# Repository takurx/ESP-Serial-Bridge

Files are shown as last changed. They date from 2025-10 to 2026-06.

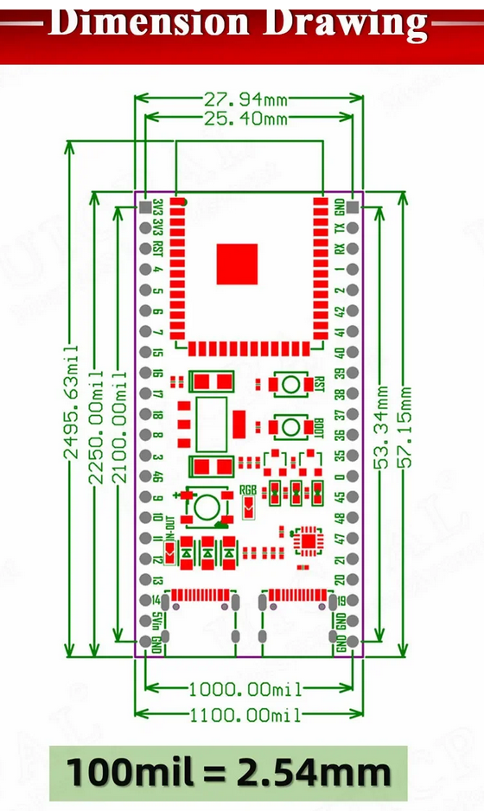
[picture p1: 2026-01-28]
pcb_kicad/esp32s3_serial_bridge_pcb/memo/スクリーンショット 2026-01-28 132533.png

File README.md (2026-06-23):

# ESP32-Serial-Bridge, ESP32S3-Serial-Bridge, 3 port concurrent

---

# Takurx's Notes

## Project Overview

This repository is a fork of [AlphaLima/ESP32-Serial-Bridge](https://github.com/AlphaLima/ESP32-Serial-Bridge) (via [Yuri's fork](https://github.com/yuri-rage/ESP32-Serial-Bridge)).  
It provides a transparent WiFi (TCP/UDP) ↔ multi-UART bridge, targeting both ESP32 and **ESP32-S3** boards.

In addition to the original/Yuri functionality, this fork adds:

- ESP32-S3 (PlatformIO) support for Bridge (Host) and Client
- 3-UART concurrent client (`Kerberos`)
- Hardware flow control (CTS/RTS) pin definitions
- Buffer size tuning for high-throughput stability
- Non-blocking TX with pending queue
- PCB design (KiCad) for ESP32 and ESP32-S3
- 3D-printable enclosure STL files
- Speed test scripts and result logs

---

## Repository Structure

```
ESP-Serial-Bridge/
├── ESP-Serial-Bridge/                        # Original Arduino IDE sketch (ESP32/ESP8266)
│   ├── ESP-Serial-Bridge.ino
│   └── config.h
│
├── ESP32-Serial-WiFi-Client/                 # Arduino IDE single-UART TCP/UDP Client (Yuri)
│   ├── ESP32-Serial-WiFi-Client.ino
│   └── client_config.h
│
├── ESP32-Serial-WiFi-Client-Kerberos/        # Arduino IDE 3-UART concurrent Client (ESP32)
│   ├── ESP32-Serial-WiFi-Client-Kerberos.ino
│   └── client_config.h
│
├── pio-ESP32S3-Serial-WiFi-Bridge/           # PlatformIO Bridge (Host) for ESP32-S3
│   ├── src/main.cpp
│   ├── include/config.h
│   └── platformio.ini
│
├── pio-ESP32S3-Serial-WiFi-Client-Kerberos/  # PlatformIO 3-UART Client (Kerberos) for ESP32-S3
│   ├── src/main.cpp
│   ├── include/client_config.h
│   └── platformio.ini
│
├── pcb_kicad/
│   ├── esp_serial_bridge_pcb/                # KiCad PCB for ESP32
│   └── esp32s3_serial_bridge_pcb/            # KiCad PCB for ESP32-S3 (Kerberos)
│
├── case_3dprint/                             # 3D-printable enclosure STL files
├── speed_test_script/                        # Python speed-test scripts and result logs
└── README.md
```

---

## Recent Updates (Takurx)

### English

#### **Near Full-Speed 3-Port Operation Achieved (Jun 2026)**
Applied buffer optimizations (developed for the Bridge/Host) to the Client (Kerberos) side.  
Result: all three UARTs now operate at **≈ 110,000–115,200 bps** in both directions simultaneously.

- Host → Client (×3 ports): ≈ **110,000 bps** (previously ≈ 13,000 bps)
- Client → Host (×3 ports): ≈ **115,200 bps** (stable)

Key changes:
- `setRxBufferSize(4096)` / `setTxBufferSize(4096)` applied to all UART ports before `begin()`
- Non-blocking TX: `availableForWrite()` used to avoid blocking `write()` calls
- Overflow data stored in a per-channel `txPendingBuf[]` queue and flushed next loop
- Bulk TCP read using `readBytes()` instead of byte-by-byte loop

#### **Buffer Separation: SOFTWAREBUFFERSIZE / HARDWAREBUFFERSIZE (Jun 2026)**
Separated buffer constant into two named constants in `config.h` for clarity:

| Constant | Size | Role |
|---|---|---|
| `HARDWAREBUFFERSIZE` | 4096 B | HardwareSerial internal ring buffer (ISR ← UART FIFO) |
| `SOFTWAREBUFFERSIZE` | 1024 B | Application working buffer (`buf1`, `buf2`, `txPending`) |

Data flow:
```
[UART RX] UART HW FIFO (1024B) → HardwareSerial ring buffer (4096B) → buf2[1024B] → TCP TX
[TCP RX]  TCP RX buffer (lwIP) → buf1[1024B] → HardwareSerial TX ring buffer (4096B) → UART TX
```

#### **pio-ESP32S3-Serial-WiFi-Client-Kerberos — 3-UART PlatformIO Client (Apr 2026)**
Added a PlatformIO version of the 3-UART concurrent client for ESP32-S3.  
Mirrors the same buffer/non-blocking approach as the Bridge Host side.

#### **PCB Design (KiCad) (Mar 2026)**
Added KiCad PCB designs (schematic + layout + Gerber) for:
- `esp_serial_bridge_pcb` — for ESP32 modules
- `esp32s3_serial_bridge_pcb` — for ESP32-S3 modules (Kerberos)

#### **pio-ESP32S3-Serial-WiFi-Bridge — ESP32-S3 PlatformIO Port (Feb 2026)**
New PlatformIO project targeting **RYMCU ESP32-S3-DevKitC-1** (board: `rymcu-esp32-s3-devkitc-1`).

Notable changes from original:
- All 3 UART ports configured with CTS/RTS pins (flow control disabled by default, can be enabled)
- `HARDWAREBUFFERSIZE` = 4096 bytes applied via `setRxBufferSize()` / `setTxBufferSize()`
- Non-blocking TX pending queue (`txPending[]`, `txPendingLen[]`) per UART port
- Bulk TCP read with `readBytes()` instead of 1-byte-at-a-time loop
- Hostname changed to `ESP32-S3`

#### **3-UART Concurrent Client — "Kerberos" (Feb 2026)**
Added `ESP32-Serial-WiFi-Client-Kerberos` (Arduino IDE) and its PlatformIO equivalent.  
Establishes three simultaneous TCP connections (one per UART) to the Bridge Host.

#### **Speed Test Results Summary**

| Date | Config | Host → Client | Client → Host |
|---|---|---|---|
| Dec 2025 | ESP32 AP mode, 1 port, flow ctrl None | ≈ 13,000 bps (drops to 7,000) | ≈ 100,000 bps (stable) |
| Feb 2026 | ESP32-S3 ↔ ESP32-S3, 1 port, flow ctrl ON | avg ≈ 82,000 bps | avg ≈ 20,000 bps |
| Feb 2026 | ESP32-S3 ↔ ESP32-S3, 1 port, flow ctrl OFF | avg ≈ 50,000 bps | avg ≈ 20,000 bps |
| Feb 2026 | ESP32-S3 ↔ ESP32-S3, 3 ports, flow ctrl None | 600–45,000 bps | 7,000–13,000 bps |
| Feb 2026 | 3 ports, flow ctrl ON/OFF | ≈ 13,000 bps avg | ≈ 10,000 bps avg |
| **Jun 2026** | **3 ports, buffer opt. applied to client**, flow ctrl None | **≈ 110,000 bps** | **≈ 115,200 bps** |

#### **Watch Dog Timer Bug Fix (Dec 2025)**
Fixed a critical bug where the system would enter an infinite loop when the Host side crashed and the Watch Dog Timer failed to activate. Now properly handles three scenarios:
1. Client-side crash (Client Reset) → Recovers with input from Host side
2. Host-side crash with quick recovery (Host Reset) → System continues normally
3. Host-side crash without recovery (Host OFF) → Client automatically resets every 30 seconds via Watch Dog Timer

#### **3D-Printable Case (Dec 2025)**
Added STL files for 3D-printable enclosure (box and cover, including v2 versions).

---

### 日本語

#### **3ポート同時フルスピード動作を達成 (2026年6月)**
Bridge（Host）側で開発したバッファ最適化手法をClient（Kerberos）側にも適用。  
全3ポートで**約110,000〜115,200 bps**の双方向同時通信が可能になった。

- Host → Client（×3ポート）: 約 **110,000 bps**（以前は約13,000 bps）
- Client → Host（×3ポート）: 約 **115,200 bps**（安定）

主な変更点：
- `setRxBufferSize(4096)` / `setTxBufferSize(4096)` を全UARTポートの `begin()` 前に適用
- 非ブロッキングTX: `availableForWrite()` でブロッキング `write()` を回避
- 書けなかったデータをポートごとの `txPendingBuf[]` キューに退避し次ループで再送
- TCPの一括読み出し（`readBytes()`）で1バイトずつのループを排除

#### **バッファ定数の分離: SOFTWAREBUFFERSIZE / HARDWAREBUFFERSIZE (2026年6月)**
`config.h` のバッファ定数を2つに分離して明確化：

| 定数 | サイズ | 役割 |
|---|---|---|
| `HARDWAREBUFFERSIZE` | 4096 B | HardwareSerial内部リングバッファ（ISR ← UART FIFO） |
| `SOFTWAREBUFFERSIZE` | 1024 B | アプリ作業バッファ（`buf1`, `buf2`, `txPending`） |

#### **pio-ESP32S3-Serial-WiFi-Client-Kerberos — 3UART PlatformIOクライアント (2026年4月)**
ESP32-S3向け3UART同時クライアントのPlatformIO版を追加。  
BridgeHost側と同じバッファ/非ブロッキング手法を適用。

#### **PCB設計（KiCad）(2026年3月)**
以下のKiCad PCB設計（回路図 + レイアウト + Gerber）を追加：
- `esp_serial_bridge_pcb` — ESP32モジュール用
- `esp32s3_serial_bridge_pcb` — ESP32-S3モジュール（Kerberos）用

#### **pio-ESP32S3-Serial-WiFi-Bridge — ESP32-S3 PlatformIO移植 (2026年2月)**
ESP32-S3（RYMCU ESP32-S3-DevKitC-1）向けの新しいPlatformIOプロジェクト。

主な変更点：
- 全3 UARTポートにCTS/RTSピンを定義（デフォルトはフロー制御無効）
- `HARDWAREBUFFERSIZE` = 4096バイトをRX/TXバッファ両方に適用
- ポートごとの非ブロッキング送信保留キュー（`txPending[]`）を実装
- TCP一括読み出しに変更（`readBytes()` 使用）
- ホスト名を `ESP32-S3` に変更

#### **3UART同時クライアント「Kerberos」(2026年2月)**
3つのTCP接続を同時確立するクライアント `ESP32-Serial-WiFi-Client-Kerberos`（Arduino IDE版）とそのPlatformIO版を追加。

#### **速度テスト結果サマリ**

| 日付 | 構成 | Host → Client | Client → Host |
|---|---|---|---|
| 2025年12月 | ESP32 APモード、1ポート、フロー制御なし | 約13,000 bps（時々7,000に低下） | 約100,000 bps（安定） |
| 2026年2月 | ESP32-S3同士、1ポート、フロー制御あり | 平均 約82,000 bps | 平均 約20,000 bps |
| 2026年2月 | ESP32-S3同士、1ポート、フロー制御なし | 平均 約50,000 bps | 平均 約20,000 bps |
| 2026年2月 | ESP32-S3同士、3ポート同時、フロー制御なし | 600〜45,000 bps | 7,000〜13,000 bps |
| 2026年2月 | 3ポート、フロー制御あり/なし | 平均 約13,000 bps | 平均 約10,000 bps |
| **2026年6月** | **3ポート、クライアント側バッファ最適化適用後**、フロー制御なし | **約110,000 bps** | **約115,200 bps** |

#### **Watch Dog Timer バグ修正 (2025年12月)**
Host側が落ちた時に無限ループに陥り、Watch Dog Timerが効かなかった重大なバグを修正。以下の3つのケースに対応:
1. Client側が落ちた場合（ClientのReset）→ Host側からの入力で回復
2. Host側が落ちてすぐ回復した場合（HostのReset）→ 正常動作
3. Host側が落ちて回復しない場合（HostのOFF）→ 30秒ごとにWatch Dog TimerでClientを自動Reset

#### **3Dプリント用ケース (2025年12月)**
3Dプリント可能なケースのSTLファイルを追加（ボックスとカバー、v2バージョンを含む）。

---

## Hardware: ESP32-S3 Pin Assignment

### Bridge Host (`pio-ESP32S3-Serial-WiFi-Bridge`)

| Port | RX Pin | TX Pin | CTS Pin | RTS Pin | TCP Port | UDP Port |
|---|---|---|---|---|---|---|
| COM0 | GPIO1 | GPIO43 | GPIO16 | GPIO15 | 8880 | 14550 |
| COM1 | GPIO18 | GPIO17 | GPIO10 | GPIO9  | 8881 | 14551 |
| COM2 | GPIO38 | GPIO37 | GPIO36 | GPIO35 | 8882 | 14552 |

- Static IP (AP mode): `192.168.4.1`
- Default SSID: `ssid_esp_uart_bridge3x3`
- Hardware flow control: pins defined, **disabled by default** (comment in code to enable)

---

# Yuri's Notes

This fork is compatible with both the ESP32 and ESP8266.

Because the ESP8266 has some idiosyncrasies with its hardware serial ports, I used SoftwareSerial to implement the ESP8266 bridge.  It is limited to ~115200 baud and will likely prove less reliable than an ESP32. `BLUETOOTH` (hardware limitation) and `PROTOCOL_UDP` (software limitation) are not available on the ESP8266.

As is, the sketch will compile, build, and upload without errors for the ESP32.  Edit `config.h` to configure and build for ESP8266.

There are many configurable parameters in `config.h`. Edit to suit your needs - inline comments should provide clarity.

## Major update, Apr 2023:
* Fixed compatibility with Arduino framework 2.0
* Added compatibility with PlatformIO.
* Implemented `PROTOCOL_UDP` (UDP broadcast)
* `PROTOCOL_TCP` and `PROTOCOL_UDP` can be used simultaneously, though doing so may result in serial traffic conflicts if your client connections are not managed carefully.
* Added `ESP32-Serial-WiFi-Client.ino` in a separate sketch folder to make an ESP32 TCP or UDP client that connects to the ESP-Serial-Bridge. Edit `client_config.h` and upload to a second board.
* Multiple bugs (possible buffer overruns) are fixed in the latest commit(s).
* Latest commits also include some styling/readability edits, though I can easily admit that it isn't the "prettiest" of C++ projects.

---

# ESP32-Serial-Bridge (Original by AlphaLima)

Transparent WiFi (TCP) to all three UART Bridge, supports both AP and STATION WiFi modes. The .ino file is the code for the ESP32. Use Arduino IDE for ESP32 to compile and upload it to the ESP32.
I made this project in order to connect Flight equipment devices devices like (Radio, Vario FLARM), to a Flight Computer (Kobo, Smartphones etc.),  but it is not limited to that. You can use it wherever you want, but on your own risk. Read license file for more details.                                  

===============================================================

Used Libraries: (must be installed in the arduino IDE):

https://github.com/espressif/arduino-esp32

===============================================================

In some cases the memorylayout is to small for this scetch.
If you face this problem you can either disable Bluetooth by removing
#define BLUETOOTH
in config.h 
or change the partition size as described here:
https://desire.giesecke.tk/index.php/2018/04/20/change-partition-size-arduino-ide/

Arduino hardware configuration:

https://github.com/AlphaLima/ESP32-Serial-Bridge/blob/master/Settings.jpg

===============================================================

example usecases:

https://www.youtube.com/watch?v=K2Hia06IMtk

https://www.youtube.com/watch?v=GoSxlQvuAhg

# Hardware (Original ESP32)
here is the wiring diagram recomendation:
https://raw.githubusercontent.com/AlphaLima/ESP32-Serial-Bridge/master/ESP32-SerialBridge.jpg             
Pinning                                                                                     
COM0 Rx <-> GPIO21                                                                               
COM0 Tx <-> GPIO01                                                                                 
COM1 Rx <-> GPIO16                                                                               
COM1 Tx <-> GPIO17                                                                              
COM2 Rx <-> GPIO15                                                                               
COM2 Tx <-> GPIO04                                                                              

NOTE: The PIN assignment has changed and may not look straigt forward (other PINs are marke as Rx/Tx), but this assignment allows to flash via USB also with hooked MAX3232 serial drivers.

I recomend to start your project with a Node32s or compatible evaluation board. For a TTL to RS232 level conversion search google for "TTL RS3232 Converter"

https://tech.scargill.net/wp-content/uploads/2017/05/ESP326.jpg

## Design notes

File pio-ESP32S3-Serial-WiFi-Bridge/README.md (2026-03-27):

# pio-ESP32S3-Serial-WiFi-Bridge

## memo randomly

- data flow
- UART HW FIFO (1024B) → HardwareSerial リングバッファ (4096B) → buf2[1024B] → TCP送信
- TCP RXバッファ（lwIP / WiFiClient内部） → buf1[SOFTWAREBUFFERSIZE] → HardwareSerial TXリングバッファ（既定256B） → UART HW FIFO（ESP32-S3は1024B） → UART TXピン

- buffer description
サイズ	役割
setRxBufferSize(HARDWAREBUFFERSIZE)	4096 bytes	HardwareSerial 内部リングバッファ — ISR が UART FIFO からここへコピーする。loop() が来るまでデータを溜める場所
buf2[NUM_COM][SOFTWAREBUFFERSIZE]	1024 bytes	loop() 内の一時作業バッファ — リングバッファから読み出してTCPへ書くための中継
buf1[NUM_COM][SOFTWAREBUFFERSIZE]	1024 bytes	TCP から読んでシリアルへ書くための中継

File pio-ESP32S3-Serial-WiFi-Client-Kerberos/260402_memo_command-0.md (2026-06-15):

# 260402_memo_command-0.md

## command1
pio-ESP32S3-Serial-WiFi-Bridge/src/main.cppのRX/TXのbufferの拡張、TXのchunk sizeの縮小などの変更した処理を、pio-ESP32S3-Serial-WiFi-Client-Kerberos/src/main.cppの方にも反映させてみてください

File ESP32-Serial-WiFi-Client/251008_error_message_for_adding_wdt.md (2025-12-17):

# 251008_error_message_for_adding_wdt.md

## cycle 1
```
C:\250602_Works\250602_GitLab\ESP-Serial-Bridge\ESP32-Serial-WiFi-Client\ESP32-Serial-WiFi-Client.ino: In function 'void setup()':
C:\250602_Works\250602_GitLab\ESP-Serial-Bridge\ESP32-Serial-WiFi-Client\ESP32-Serial-WiFi-Client.ino:80:23: error: too many arguments to function 'hw_timer_t* timerBegin(uint32_t)'
   80 |     timer = timerBegin(0, 80, true);                  //timer 0, div 80
      |             ~~~~~~~~~~^~~~~~~~~~~~~
In file included from C:\Users\YoshihiroNakagawa\AppData\Local\Arduino15\packages\esp32\hardware\esp32\3.3.0\cores\esp32/esp32-hal.h:98,
                 from C:\Users\YoshihiroNakagawa\AppData\Local\Arduino15\packages\esp32\hardware\esp32\3.3.0\cores\esp32/Arduino.h:44,
                 from C:\250602_Works\250602_GitLab\ESP-Serial-Bridge\ESP32-Serial-WiFi-Client\ESP32-Serial-WiFi-Client.ino:12:
C:\Users\YoshihiroNakagawa\AppData\Local\Arduino15\packages\esp32\hardware\esp32\3.3.0\cores\esp32/esp32-hal-timer.h:35:13: note: declared here
   35 | hw_timer_t *timerBegin(uint32_t frequency);
      |             ^~~~~~~~~~
C:\250602_Works\250602_GitLab\ESP-Serial-Bridge\ESP32-Serial-WiFi-Client\ESP32-Serial-WiFi-Client.ino:81:25: error: too many arguments to function 'void timerAttachInterrupt(hw_timer_t*, void (*)())'
   81 |     timerAttachInterrupt(timer, &resetModule, true);  //attach callback
      |     ~~~~~~~~~~~~~~~~~~~~^~~~~~~~~~~~~~~~~~~~~~~~~~~
C:\Users\YoshihiroNakagawa\AppData\Local\Arduino15\packages\esp32\hardware\esp32\3.3.0\cores\esp32/esp32-hal-timer.h:50:6: note: declared here
   50 | void timerAttachInterrupt(hw_timer_t *timer, void (*userFunc)(void));
      |      ^~~~~~~~~~~~~~~~~~~~
C:\250602_Works\250602_GitLab\ESP-Serial-Bridge\ESP32-Serial-WiFi-Client\ESP32-Serial-WiFi-Client.ino:82:5: error: 'timerAlarmWrite' was not declared in this scope; did you mean 'timerWrite'?
   82 |     timerAlarmWrite(timer, TIMEOUT * 1000, false);    //set time in us
      |     ^~~~~~~~~~~~~~~
      |     timerWrite
C:\250602_Works\250602_GitLab\ESP-Serial-Bridge\ESP32-Serial-WiFi-Client\ESP32-Serial-WiFi-Client.ino:83:5: error: 'timerAlarmEnable' was not declared in this scope; did you mean 'timerAlarm'?
   83 |     timerAlarmEnable(timer);                          //enable interrupt
      |     ^~~~~~~~~~~~~~~~
      |     timerAlarm
exit status 1

Compilation error: too many arguments to function 'hw_timer_t* timerBegin(uint32_t)'
```

## cycle 2
```
C:\250602_Works\250602_GitLab\ESP-Serial-Bridge\ESP32-Serial-WiFi-Client\ESP32-Serial-WiFi-Client.ino:34:1: error: expected ',' or ';' before 'hw_timer_t'
   34 | hw_timer_t *timer = NULL;
      | ^~~~~~~~~~
C:\250602_Works\250602_GitLab\ESP-Serial-Bridge\ESP32-Serial-WiFi-Client\ESP32-Serial-WiFi-Client.ino: In function 'void setup()':
C:\250602_Works\250602_GitLab\ESP-Serial-Bridge\ESP32-Serial-WiFi-Client\ESP32-Serial-WiFi-Client.ino:80:5: error: 'timer' was not declared in this scope; did you mean 'time'?
   80 |     timer = timerBegin(1000000);                       //timer 1MHz
      |     ^~~~~
      |     time
C:\250602_Works\250602_GitLab\ESP-Serial-Bridge\ESP32-Serial-WiFi-Client\ESP32-Serial-WiFi-Client.ino: In function 'void loop()':
C:\250602_Works\250602_GitLab\ESP-Serial-Bridge\ESP32-Serial-WiFi-Client\ESP32-Serial-WiFi-Client.ino:150:16: error: 'timer' was not declared in this scope; did you mean 'time'?
  150 |     timerWrite(timer, 0); //reset timer (feed watchdog)
      |                ^~~~~
      |                time
exit status 1

Compilation error: expected ',' or ';' before 'hw_timer_t'
```

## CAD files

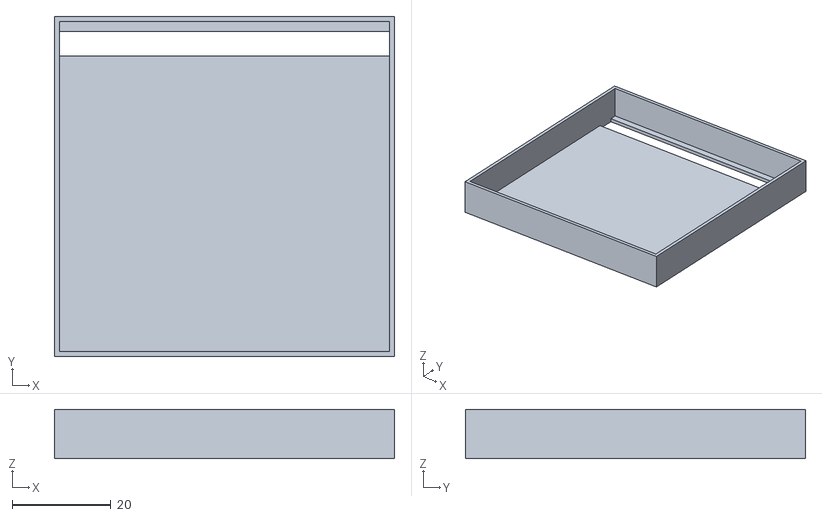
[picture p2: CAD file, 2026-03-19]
case_3dprint/260313_v1_cover_box_ESP32S3_Serial_WiFi_Bridge_Kerberos.stl
69.0 x 69.0 x 10.0

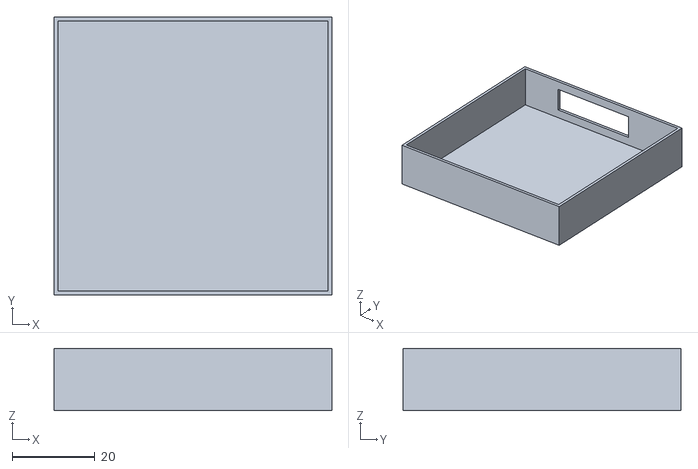
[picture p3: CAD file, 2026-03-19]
case_3dprint/260313_v1_box_ESP32S3_Serial_WiFi_Bridge_Kerberos.stl
67.0 x 67.0 x 15.0

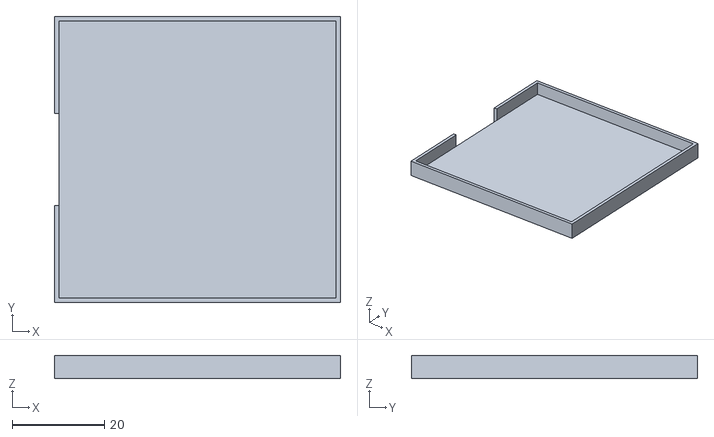
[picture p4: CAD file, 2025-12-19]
case_3dprint/251216_ESP32_uart_bridge_box_cover_v2.stl
62.0 x 62.0 x 5.00

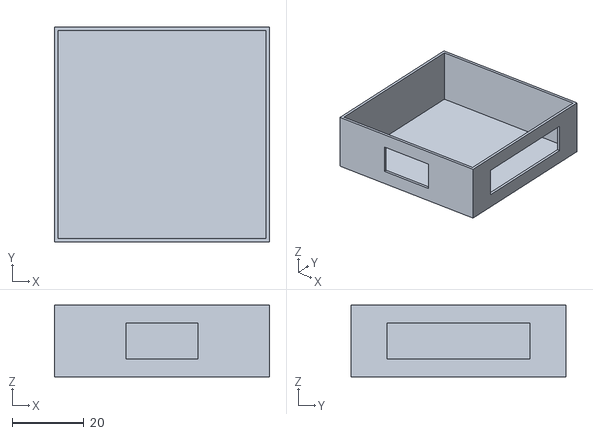
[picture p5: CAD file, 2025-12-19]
case_3dprint/251215_ESP32_uart_bridge_box.stl
60.0 x 60.0 x 20.0

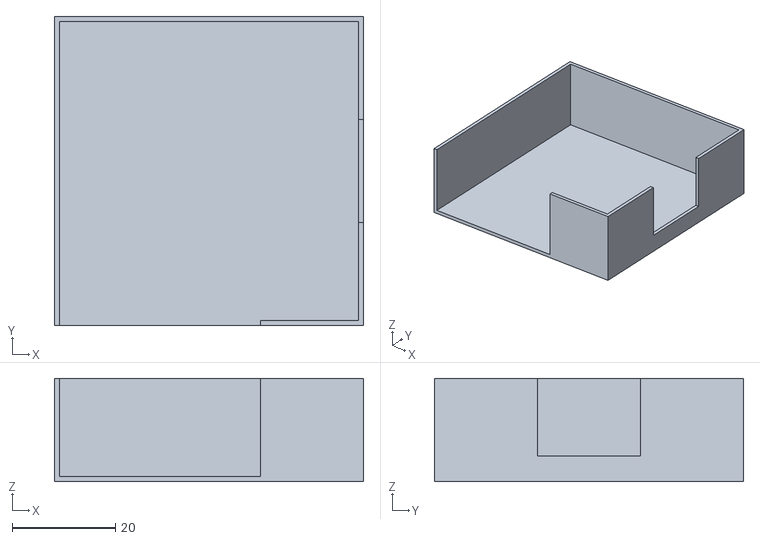
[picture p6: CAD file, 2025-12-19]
case_3dprint/251216_ESP32_uart_bridge_box_v2.stl
60.0 x 60.0 x 20.0

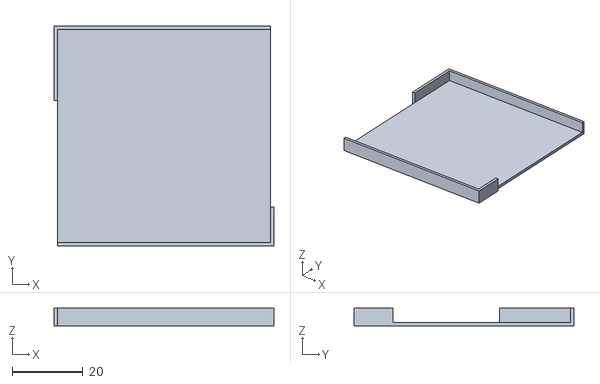
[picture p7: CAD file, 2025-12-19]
case_3dprint/251215_ESP32_uart_bridge_box_cover.stl
62.0 x 62.0 x 5.00

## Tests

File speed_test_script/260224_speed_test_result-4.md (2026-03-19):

# 260224_speed_test_result-4.md

## conditions
- ESP32-S3(host) - ESP32-S3(client)
- pio-ESP32S3-Serial-WiFi-Bridge - pio-ESP32S3-Serial-WiFi-Client-Kerberos

## summary
- flow controlありの方が気持ち速そう
- flow controlあり
  - host -> client, Average 82000 bps
  - host <- client, Average 20000 bps
- flow controlなし
  - host -> client, average 50000 bps
  - host <- client, Average 20000 bps

- ESP32S3の方がhost <- clientの速度が速くて良さそう、また速度が逆の結果ではある
- vs ESP32, 251218
  - Host -> Client: around 13000 bps, たまに7000 pbs
  - Client -> Host: around 100000 bps, 安定

## test1, uart2-com18(host) -> uart2-com29(client), flow control: enabled
- Average 82000 bps, max 108000 bps, min 3500 bps

```
PS C:\250602_Works\250602_GitLab\ESP-Serial-Bridge\speed_test_script> python .\test1_receive_random.py 
3538.78 bps                                                                             
32671.13 bps
77831.97 bps
50005.55 bps
58108.27 bps
59497.78 bps
66487.22 bps
23099.88 bps
38286.39 bps
70974.22 bps
77033.33 bps
80240.13 bps
78274.95 bps
85029.61 bps
80010.75 bps
79048.20 bps
96127.66 bps
89747.27 bps
88844.89 bps
89882.67 bps
96622.58 bps
87002.68 bps
101059.81 bps
105203.01 bps
99724.88 bps
97454.75 bps
102391.41 bps
106546.77 bps
108124.37 bps
87587.94 bps
91371.89 bps
41076.35 bps
78954.53 bps
79964.78 bps
99334.86 bps
67170.67 bps
70372.86 bps
78913.38 bps
78724.66 bps
86967.95 bps
78917.57 bps
79282.09 bps
79094.87 bps
76795.18 bps
88044.04 bps
88784.61 bps
96418.29 bps
96521.74 bps
99536.73 bps
100045.17 bps
95527.63 bps
104900.18 bps
100113.71 bps
48213.42 bps
99794.33 bps
103437.76 bps
101754.82 bps
97536.30 bps
```

## test2, uart2-com18(host) <- uart2-com29(client), flow control: enabled
- Average 20000 bps, max 45000 bps, min 3000 bps

```
PS C:\250602_Works\250602_GitLab\ESP-Serial-Bridge\speed_test_script> python .\test1_receive_random.py
3093.23 bps
45183.01 bps
13730.60 bps
27579.84 bps
16415.60 bps
19765.85 bps
13921.65 bps
16426.43 bps
35207.73 bps
13605.49 bps
13789.07 bps
27787.25 bps
27249.54 bps
13880.87 bps
13761.62 bps
19383.92 bps
27522.93 bps
13814.08 bps
13635.89 bps
13772.15 bps
13753.68 bps
13736.68 bps
32545.46 bps
13737.50 bps
27304.04 bps
13780.52 bps
27373.26 bps
13823.80 bps
16385.23 bps
```

## test3, uart2-com18(host) -> uart2-com29(client), flow control: disabled
- average 50000 bps, max 115000 bps, min 2000 bps

```
PS C:\250602_Works\250602_GitLab\ESP-Serial-Bridge\speed_test_script> python .\test1_receive_random.py
2177.55 bps
115064.37 bps
115139.91 bps
104006.52 bps
37358.19 bps
14603.29 bps
24947.27 bps
20611.27 bps
14594.36 bps
12743.75 bps
20594.07 bps
20288.62 bps
14616.75 bps
20757.68 bps
12822.62 bps
20606.84 bps
28547.43 bps
12657.10 bps
14689.66 bps
20579.03 bps
12744.59 bps
14613.41 bps
20577.66 bps
12628.76 bps
14762.19 bps
12209.61 bps
```

## test4, uart2-com18(host) <- uart2-com29(client), flow control: disabled
- Average 20000 bps, max 100000 bps, min 3000 bps

```
PS C:\250602_Works\250602_GitLab\ESP-Serial-Bridge\speed_test_script> python .\test1_receive_random.py
3307.27 bps
105561.38 bps
9791.88 bps
13586.41 bps
13768.07 bps
20189.73 bps
33626.77 bps
16628.27 bps
19842.49 bps
102550.38 bps
7385.27 bps
13920.94 bps
13824.53 bps
39914.20 bps
13980.38 bps
13536.02 bps
19684.80 bps
28334.70 bps
13812.42 bps
98962.45 bps
90582.25 bps
80638.94 bps
14375.85 bps
32974.44 bps
35345.13 bps
13802.42 bps
52150.37 bps
16809.83 bps
28217.62 bps
13661.30 bps
25906.35 bps
```

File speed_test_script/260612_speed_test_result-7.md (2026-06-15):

# 260612_speed_test_result-7.md

## test1, host x3 -> client x3, ほぼ110000 bps
- com11 -> com8
```
(.venv) PS C:\250602_Works\250602_GitLab\ESP-Serial-Bridge> cd .\speed_test_script\
(.venv) PS C:\250602_Works\250602_GitLab\ESP-Serial-Bridge\speed_test_script> python .\test1_send_random_com11.py         
Traceback (most recent call last):
  File "C:\250602_Works\250602_GitLab\ESP-Serial-Bridge\speed_test_script\test1_send_random_com11.py", line 12, in <module>
    ser.write(os.urandom(1024))
    ~~~~~~~~~^^^^^^^^^^^^^^^^^^
  File "C:\250602_Works\250602_GitLab\ESP-Serial-Bridge\.venv\Lib\site-packages\serial\serialwin32.py", line 321, in write
    win32.GetOverlappedResult(self._port_handle, self._overlapped_write, ctypes.byref(n), True)
    ~~~~~~~~~~~~~~~~~~~~~~~~~^^^^^^^^^^^^^^^^^^^^^^^^^^^^^^^^^^^^^^^^^^^^^^^^^^^^^^^^^^^^^^^^^^
KeyboardInterrupt
(.venv) PS C:\250602_Works\250602_GitLab\ESP-Serial-Bridge\speed_test_script>
```

```
(.venv) PS C:\250602_Works\250602_GitLab\ESP-Serial-Bridge> cd .\speed_test_script\
(.venv) PS C:\250602_Works\250602_GitLab\ESP-Serial-Bridge\speed_test_script> python .\test1_receive_random_com8.py        
78904.37 bps
118948.96 bps
118935.09 bps
108012.09 bps
118890.13 bps
109074.76 bps
118993.17 bps
118980.43 bps
108985.46 bps
119026.42 bps
118868.41 bps
109074.15 bps
118933.56 bps
109093.45 bps
118957.71 bps
118971.28 bps
109073.04 bps
118921.73 bps
118952.31 bps
109042.43 bps
118919.40 bps
109062.70 bps
118947.09 bps
118953.07 bps
109057.76 bps
118981.41 bps
118940.09 bps
109033.70 bps
118941.63 bps
109083.19 bps
118934.55 bps
118943.19 bps
109058.79 bps
118939.84 bps
118973.59 bps
107710.14 bps
118934.79 bps
109054.84 bps
Traceback (most recent call last):
  File "C:\250602_Works\250602_GitLab\ESP-Serial-Bridge\speed_test_script\test1_receive_random_com8.py", line 14, in <module>
    data = ser.read(1024)
  File "C:\250602_Works\250602_GitLab\ESP-Serial-Bridge\.venv\Lib\site-packages\serial\serialwin32.py", line 288, in read
    result_ok = win32.GetOverlappedResult(
        self._port_handle,
        ctypes.byref(self._overlapped_read),
        ctypes.byref(rc),
        True)
KeyboardInterrupt
(.venv) PS C:\250602_Works\250602_GitLab\ESP-Serial-Bridge\speed_test_script> 
```

- com12 -> com9
```
(.venv) PS C:\250602_Works\250602_GitLab\ESP-Serial-Bridge> cd .\speed_test_script\
(.venv) PS C:\250602_Works\250602_GitLab\ESP-Serial-Bridge\speed_test_script> python .\test1_send_random_com12.py      
Traceback (most recent call last):
  File "C:\250602_Works\250602_GitLab\ESP-Serial-Bridge\speed_test_script\test1_send_random_com12.py", line 12, in <module>
    ser.write(os.urandom(1024))
    ~~~~~~~~~^^^^^^^^^^^^^^^^^^
  File "C:\250602_Works\250602_GitLab\ESP-Serial-Bridge\.venv\Lib\site-packages\serial\serialwin32.py", line 321, in write
    win32.GetOverlappedResult(self._port_handle, self._overlapped_write, ctypes.byref(n), True)
    ~~~~~~~~~~~~~~~~~~~~~~~~~^^^^^^^^^^^^^^^^^^^^^^^^^^^^^^^^^^^^^^^^^^^^^^^^^^^^^^^^^^^^^^^^^^
KeyboardInterrupt
(.venv) PS C:\250602_Works\250602_GitLab\ESP-Serial-Bridge\speed_test_script> 
```

```
(.venv) PS C:\250602_Works\250602_GitLab\ESP-Serial-Bridge> cd .\speed_test_script\
(.venv) PS C:\250602_Works\250602_GitLab\ESP-Serial-Bridge\speed_test_script> python .\test1_receive_random_com9.py 
79276.25 bps
118922.99 bps
117907.55 bps
109042.28 bps
118940.42 bps
109035.89 bps
118983.94 bps
118923.49 bps
109093.57 bps
118917.09 bps
118935.20 bps
109072.29 bps
118956.84 bps
109047.62 bps
118960.95 bps
118921.89 bps
109094.30 bps
118927.85 bps
118955.90 bps
109043.92 bps
118968.01 bps
109120.15 bps
118949.45 bps
118958.04 bps
109044.50 bps
118944.34 bps
118955.08 bps
109043.92 bps
118925.41 bps
109046.26 bps
118943.05 bps
118919.54 bps
109048.17 bps
118961.53 bps
118915.12 bps
109058.57 bps
Traceback (most recent call last):
  File "C:\250602_Works\250602_GitLab\ESP-Serial-Bridge\speed_test_script\test1_receive_random_com9.py", line 14, in <module>
    data = ser.read(1024)
  File "C:\250602_Works\250602_GitLab\ESP-Serial-Bridge\.venv\Lib\site-packages\serial\serialwin32.py", line 288, in read
    result_ok = win32.GetOverlappedResult(
        self._port_handle,
        ctypes.byref(self._overlapped_read),
        ctypes.byref(rc),
        True)
KeyboardInterrupt
(.venv) PS C:\250602_Works\250602_GitLab\ESP-Serial-Bridge\speed_test_script> 
```

- com13 -> com14
```
(.venv) PS C:\250602_Works\250602_GitLab\ESP-Serial-Bridge> cd .\speed_test_script\
(.venv) PS C:\250602_Works\250602_GitLab\ESP-Serial-Bridge\speed_test_script> python .\test1_send_random_com13.py   
Traceback (most recent call last):
  File "C:\250602_Works\250602_GitLab\ESP-Serial-Bridge\speed_test_script\test1_send_random_com13.py", line 12, in <module>
    ser.write(os.urandom(1024))
    ~~~~~~~~~^^^^^^^^^^^^^^^^^^
  File "C:\250602_Works\250602_GitLab\ESP-Serial-Bridge\.venv\Lib\site-packages\serial\serialwin32.py", line 321, in write
    win32.GetOverlappedResult(self._port_handle, self._overlapped_write, ctypes.byref(n), True)
    ~~~~~~~~~~~~~~~~~~~~~~~~~^^^^^^^^^^^^^^^^^^^^^^^^^^^^^^^^^^^^^^^^^^^^^^^^^^^^^^^^^^^^^^^^^^
KeyboardInterrupt
(.venv) PS C:\250602_Works\250602_GitLab\ESP-Serial-Bridge\speed_test_script> 
```

```
(.venv) PS C:\250602_Works\250602_GitLab\ESP-Serial-Bridge> cd .\speed_test_script\
(.venv) PS C:\250602_Works\250602_GitLab\ESP-Serial-Bridge\speed_test_script> python .\test1_receive_random_com14.py
79261.24 bps
118221.66 bps
118915.23 bps
109017.20 bps
118945.11 bps
109115.64 bps
118983.42 bps
118951.45 bps
109017.95 bps
118957.06 bps
118947.04 bps
109032.09 bps
118960.98 bps
109067.58 bps
118924.91 bps
118910.89 bps
109045.88 bps
118959.11 bps
118996.94 bps
109061.29 bps
118959.17 bps
109013.42 bps
118957.99 bps
119040.42 bps
109090.22 bps
118948.74 bps
118862.33 bps
109128.65 bps
118914.57 bps
109059.20 bps
118945.14 bps
118914.40 bps
109069.54 bps
112813.63 bps
118958.54 bps
Traceback (most recent call last):
  File "C:\250602_Works\250602_GitLab\ESP-Serial-Bridge\speed_test_script\test1_receive_random_com14.py", line 14, in <module>
    data = ser.read(1024)
  File "C:\250602_Works\250602_GitLab\ESP-Serial-Bridge\.venv\Lib\site-packages\serial\serialwin32.py", line 288, in read
    result_ok = win32.GetOverlappedResult(
        self._port_handle,
        ctypes.byref(self._overlapped_read),
        ctypes.byref(rc),
        True)
KeyboardInterrupt
(.venv) PS C:\250602_Works\250602_GitLab\ESP-Serial-Bridge\speed_test_script> 
```

## test2, host x3 <- client x3、ほぼ115200 bps
- com11 <- com8
```
(.venv) PS C:\250602_Works\250602_GitLab\ESP-Serial-Bridge\speed_test_script> python .\test1_receive_random_com11.py   
115474.55 bps
115230.73 bps
115233.72 bps
115200.21 bps
115255.50 bps
115236.84 bps
115246.14 bps
115226.77 bps
115204.10 bps
115229.06 bps
115240.27 bps
115193.29 bps
115251.45 bps
115220.17 bps
115250.19 bps
115220.74 bps
115210.54 bps
115234.13 bps
115235.09 bps
115225.79 bps
115237.10 bps
115212.96 bps
115213.53 bps
Traceback (most recent call last):
  File "C:\250602_Works\250602_GitLab\ESP-Serial-Bridge\speed_test_script\test1_receive_random_com11.py", line 14, in <module>
    data = ser.read(1024)
  File "C:\250602_Works\250602_GitLab\ESP-Serial-Bridge\.venv\Lib\site-packages\serial\serialwin32.py", line 288, in read
    result_ok = win32.GetOverlappedResult(
        self._port_handle,
        ctypes.byref(self._overlapped_read),
        ctypes.byref(rc),
        True)
KeyboardInterrupt
(.venv) PS C:\250602_Works\250602_GitLab\ESP-Serial-Bridge\speed_test_script> 
```

```
(.venv) PS C:\250602_Works\250602_GitLab\ESP-Serial-Bridge\speed_test_script> python .\test1_send_random_com8.py    
Traceback (most recent call last):
  File "C:\250602_Works\250602_GitLab\ESP-Serial-Bridge\speed_test_script\test1_send_random_com8.py", line 12, in <module>
    ser.write(os.urandom(1024))
    ~~~~~~~~~^^^^^^^^^^^^^^^^^^
  File "C:\250602_Works\250602_GitLab\ESP-Serial-Bridge\.venv\Lib\site-packages\serial\serialwin32.py", line 321, in write
    win32.GetOverlappedResult(self._port_handle, self._overlapped_write, ctypes.byref(n), True)
    ~~~~~~~~~~~~~~~~~~~~~~~~~^^^^^^^^^^^^^^^^^^^^^^^^^^^^^^^^^^^^^^^^^^^^^^^^^^^^^^^^^^^^^^^^^^
KeyboardInterrupt
(.venv) PS C:\250602_Works\250602_GitLab\ESP-Serial-Bridge\speed_test_script> 
```

- com12 <- com9
```
(.venv) PS C:\250602_Works\250602_GitLab\ESP-Serial-Bridge\speed_test_script> python .\test1_receive_random_com12.py
115411.69 bps
115224.60 bps
115257.53 bps
115234.93 bps
115218.16 bps
115222.64 bps
115214.22 bps
115231.25 bps
115216.75 bps
115241.97 bps
115234.88 bps
115230.91 bps
115236.35 bps
115229.60 bps
115224.29 bps
115210.38 bps
115248.00 bps
115235.45 bps
115241.14 bps
115210.90 bps
115238.80 bps
115228.90 bps
Traceback (most recent call last):
  File "C:\250602_Works\250602_GitLab\ESP-Serial-Bridge\speed_test_script\test1_receive_random_com12.py", line 14, in <module>
    data = ser.read(1024)
  File "C:\250602_Works\250602_GitLab\ESP-Serial-Bridge\.venv\Lib\site-packages\serial\serialwin32.py", line 288, in read
    result_ok = win32.GetOverlappedResult(
        self._port_handle,
        ctypes.byref(self._overlapped_read),
        ctypes.byref(rc),
        True)
KeyboardInterrupt
(.venv) PS C:\250602_Works\250602_GitLab\ESP-Serial-Bridge\speed_test_script> 
```

```
(.venv) PS C:\250602_Works\250602_GitLab\ESP-Serial-Bridge\speed_test_script> python .\test1_send_random_com9.py       
Traceback (most recent call last):
  File "C:\250602_Works\250602_GitLab\ESP-Serial-Bridge\speed_test_script\test1_send_random_com9.py", line 12, in <module>
    ser.write(os.urandom(1024))
    ~~~~~~~~~^^^^^^^^^^^^^^^^^^
  File "C:\250602_Works\250602_GitLab\ESP-Serial-Bridge\.venv\Lib\site-packages\serial\serialwin32.py", line 321, in write
    win32.GetOverlappedResult(self._port_handle, self._overlapped_write, ctypes.byref(n), True)
    ~~~~~~~~~~~~~~~~~~~~~~~~~^^^^^^^^^^^^^^^^^^^^^^^^^^^^^^^^^^^^^^^^^^^^^^^^^^^^^^^^^^^^^^^^^^
KeyboardInterrupt
(.venv) PS C:\250602_Works\250602_GitLab\ESP-Serial-Bridge\speed_test_script> 
```

- com13 <- com14
```
(.venv) PS C:\250602_Works\250602_GitLab\ESP-Serial-Bridge\speed_test_script> python .\test1_receive_random_com13.py   
115338.03 bps
115252.66 bps
115220.97 bps
115215.46 bps
115238.10 bps
115212.26 bps
115225.17 bps
115246.17 bps
115200.75 bps
115221.95 bps
115242.35 bps
115218.09 bps
115234.52 bps
115198.51 bps
115234.83 bps
115239.26 bps
115217.88 bps
115226.69 bps
115217.13 bps
115237.95 bps
115214.66 bps
115218.09 bps
115229.70 bps
115233.16 bps
Traceback (most recent call last):
  File "C:\250602_Works\250602_GitLab\ESP-Serial-Bridge\speed_test_script\test1_receive_random_com13.py", line 14, in <module>
    data = ser.read(1024)
  File "C:\250602_Works\250602_GitLab\ESP-Serial-Bridge\.venv\Lib\site-packages\serial\serialwin32.py", line 288, in read
    result_ok = win32.GetOverlappedResult(
        self._port_handle,
        ctypes.byref(self._overlapped_read),
        ctypes.byref(rc),
        True)
KeyboardInterrupt
(.venv) PS C:\250602_Works\250602_GitLab\ESP-Serial-Bridge\speed_test_script> 
```

```
(.venv) PS C:\250602_Works\250602_GitLab\ESP-Serial-Bridge\speed_test_script> python .\test1_send_random_com14.py      
Traceback (most recent call last):
  File "C:\250602_Works\250602_GitLab\ESP-Serial-Bridge\speed_test_script\test1_send_random_com14.py", line 12, in <module>
    ser.write(os.urandom(1024))
    ~~~~~~~~~^^^^^^^^^^^^^^^^^^
  File "C:\250602_Works\250602_GitLab\ESP-Serial-Bridge\.venv\Lib\site-packages\serial\serialwin32.py", line 321, in write
    win32.GetOverlappedResult(self._port_handle, self._overlapped_write, ctypes.byref(n), True)
    ~~~~~~~~~~~~~~~~~~~~~~~~~^^^^^^^^^^^^^^^^^^^^^^^^^^^^^^^^^^^^^^^^^^^^^^^^^^^^^^^^^^^^^^^^^^
KeyboardInterrupt
(.venv) PS C:\250602_Works\250602_GitLab\ESP-Serial-Bridge\speed_test_script> 
```

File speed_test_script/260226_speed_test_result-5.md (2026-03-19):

# 260226_speed_test_result-5.md
- flow controlあり
- host -> client x3, around 13000 bps
- host <- client x3, around 10000 bps

## host -> client x3
- average 13384 bps
- com3 -> com24
```
PS C:\250602_Works\250602_GitLab\ESP-Serial-Bridge\speed_test_script> python .\test1_receive_random_com24.py
8209.64 bps
7414.25 bps
20062.32 bps
26935.83 bps
6636.34 bps
15172.22 bps
12982.51 bps
12805.07 bps
16692.21 bps
17345.38 bps
16577.15 bps
13393.31 bps
12046.95 bps
14719.65 bps
15112.63 bps
13042.45 bps
13585.98 bps
14961.36 bps
11521.83 bps
14277.90 bps
13814.57 bps
12438.71 bps
7486.96 bps
14288.99 bps
6428.01 bps
14013.77 bps
14051.74 bps
6753.16 bps
14257.57 bps
20187.96 bps
6784.34 bps
14204.86 bps
```

- com6 -> com26
- average 12932 bps
```
PS C:\250602_Works\250602_GitLab\ESP-Serial-Bridge\speed_test_script> python .\test1_receive_random_com26.py
6008.63 bps
6799.82 bps
14473.51 bps
14681.49 bps
12820.54 bps
14037.50 bps
13377.27 bps
12397.13 bps
17078.60 bps
12973.63 bps
15192.65 bps
20845.26 bps
12037.01 bps
14087.21 bps
14463.62 bps
12067.55 bps
15422.94 bps
13768.99 bps
12021.22 bps
14093.63 bps
14532.63 bps
12275.56 bps
7308.08 bps
14108.37 bps
6506.10 bps
14620.84 bps
13043.42 bps
7250.04 bps
18901.30 bps
15388.48 bps
6285.60 bps
14982.36 bps
```

- com11 -> com25
- average 13259 bps
```
PS C:\250602_Works\250602_GitLab\ESP-Serial-Bridge\speed_test_script> python .\test1_receive_random_com25.py
8879.58 bps
13973.95 bps
15375.27 bps
6608.19 bps
19321.54 bps
7304.78 bps
12981.72 bps
17184.70 bps
21640.56 bps
15028.63 bps
13885.30 bps
6787.57 bps
15420.29 bps
13748.39 bps
12205.65 bps
7750.47 bps
20424.44 bps
11528.24 bps
15527.29 bps
6983.52 bps
13366.27 bps
7212.68 bps
19545.70 bps
6427.94 bps
14714.85 bps
12953.15 bps
13443.34 bps
13691.78 bps
26823.76 bps
7039.84 bps
```

## host <- client x3
- com3 <- com24
- average 9593 bps
```
PS C:\250602_Works\250602_GitLab\ESP-Serial-Bridge\speed_test_script> python .\test1_receive_random_com3.py  
2467.44 bps
12393.86 bps
9651.24 bps
1273.77 bps
7091.49 bps
7415.35 bps
4311.57 bps
8442.01 bps
8803.40 bps
7868.16 bps
11692.10 bps
7501.33 bps
6823.70 bps
7192.53 bps
7112.49 bps
17219.18 bps
14304.39 bps
7313.47 bps
13512.76 bps
7379.70 bps
12983.04 bps
11752.56 bps
7179.37 bps
7676.67 bps
12436.74 bps
7827.91 bps
12265.62 bps
6812.18 bps
14007.45 bps
7391.31 bps
19870.53 bps
12772.52 bps
7483.83 bps
12121.76 bps
7802.38 bps
12662.78 bps
7401.94 bps
11449.65 bps
7452.99 bps
7325.10 bps
6272.18 bps
13052.69 bps
8398.29 bps
19529.24 bps
11671.10 bps
7644.41 bps
6503.06 bps
7980.66 bps
12588.50 bps
```

- com6 <- com26
- average 9741 bps
```
PS C:\250602_Works\250602_GitLab\ESP-Serial-Bridge\speed_test_script> python .\test1_receive_random_com6.py 
2916.28 bps
12931.56 bps
1106.12 bps
6062.97 bps
8234.07 bps
13083.77 bps
6864.21 bps
18484.52 bps
6970.23 bps
8078.33 bps
12279.64 bps
6898.66 bps
7369.61 bps
12102.50 bps
6739.11 bps
12739.31 bps
7208.17 bps
7644.43 bps
13179.41 bps
6967.38 bps
7337.17 bps
16554.29 bps
8415.66 bps
12828.77 bps
7612.20 bps
17936.72 bps
7244.31 bps
13925.69 bps
12297.82 bps
7343.41 bps
7345.44 bps
13073.34 bps
6455.48 bps
7282.35 bps
6571.36 bps
14457.81 bps
12465.97 bps
7502.33 bps
13434.55 bps
13320.14 bps
6911.68 bps
12357.57 bps
7046.75 bps
7781.63 bps
13130.72 bps
12405.84 bps
6947.99 bps
```

- com11 <- com25
- average 9727 bps
```
PS C:\250602_Works\250602_GitLab\ESP-Serial-Bridge\speed_test_script> python .\test1_receive_random_com11.py
3858.88 bps
9344.13 bps
13865.20 bps
1266.69 bps
7127.89 bps
2872.67 bps
6859.48 bps
18935.49 bps
6522.09 bps
7116.28 bps
7450.46 bps
13141.63 bps
14423.13 bps
6109.01 bps
7891.85 bps
6797.25 bps
19283.64 bps
12657.24 bps
7713.12 bps
12197.82 bps
13515.36 bps
6797.11 bps
7385.73 bps
12410.40 bps
14388.10 bps
7423.75 bps
13052.92 bps
11332.25 bps
7663.14 bps
6884.66 bps
7586.99 bps
12130.18 bps
7663.01 bps
6411.37 bps
15017.45 bps
12330.10 bps
7843.33 bps
12900.34 bps
13846.16 bps
12758.09 bps
6689.49 bps
6721.69 bps
6997.38 bps
7482.40 bps
7049.88 bps
18531.29 bps
6503.12 bps
7575.45 bps
14338.12 bps
```

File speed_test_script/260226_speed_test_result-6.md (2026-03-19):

# 260226_speed_test_result-6.md
- flow controlなし
- host -> client x3, around 13000 bps
- host <- client x3, around 10000 bps

## host -> client x3
- average 13967 bps

- com3 -> com24
```
PS C:\250602_Works\250602_GitLab\ESP-Serial-Bridge\speed_test_script> python .\test1_receive_random_com24.py
7596.18 bps
7175.18 bps
19639.19 bps
18791.18 bps
8122.44 bps
13517.37 bps
12444.75 bps
14206.08 bps
15386.03 bps
12497.33 bps
18692.37 bps
8009.68 bps
10245.09 bps
19383.14 bps
20283.87 bps
25798.97 bps
7614.46 bps
12179.18 bps
13659.21 bps
14593.62 bps
6545.90 bps
14955.96 bps
```

- com6 -> com26
- average 13284 bps
```
PS C:\250602_Works\250602_GitLab\ESP-Serial-Bridge\speed_test_script> python .\test1_receive_random_com26.py
8855.64 bps
14918.95 bps
12900.29 bps
13026.45 bps
8224.27 bps
11504.15 bps
14826.84 bps
20563.80 bps
12833.26 bps
20899.39 bps
14135.63 bps
12717.04 bps
7341.20 bps
14701.79 bps
23033.34 bps
8126.93 bps
14004.12 bps
12100.98 bps
13705.73 bps
8408.98 bps
11714.63 bps
13713.57 bps
```

- com11 -> com25
- average 13502 bps
```
PS C:\250602_Works\250602_GitLab\ESP-Serial-Bridge\speed_test_script> python .\test1_receive_random_com25.py
13206.13 bps
13775.84 bps
12421.58 bps
7115.57 bps
23068.78 bps
12448.88 bps
14314.66 bps
14793.40 bps
16774.85 bps
15289.52 bps
14034.05 bps
12244.31 bps
7660.88 bps
14175.22 bps
19352.01 bps
14613.88 bps
7306.85 bps
17434.52 bps
7816.88 bps
19367.18 bps
6336.11 bps
```

## host <- client x3
- com3 <- com24
- average 9681 bps
```
PS C:\250602_Works\250602_GitLab\ESP-Serial-Bridge\speed_test_script> python .\test1_receive_random_com3.py 
8901.60 bps
7997.97 bps
11294.82 bps
7786.55 bps
6516.94 bps
14254.28 bps
7356.33 bps
12117.76 bps
7438.99 bps
12072.86 bps
14020.42 bps
7028.32 bps
6895.26 bps
13940.02 bps
6530.36 bps
13070.82 bps
8446.79 bps
12321.16 bps
7261.39 bps
12345.44 bps
7917.43 bps
12410.51 bps
6855.78 bps
7573.46 bps
```

- com6 <- com26
- average 9661 bps
```
PS C:\250602_Works\250602_GitLab\ESP-Serial-Bridge\speed_test_script> python .\test1_receive_random_com6.py 
13171.98 bps
6387.59 bps
6977.85 bps
7815.86 bps
12015.40 bps
7368.00 bps
7171.76 bps
17781.45 bps
7190.08 bps
7254.44 bps
14234.08 bps
12990.19 bps
6289.10 bps
7747.92 bps
13075.14 bps
13674.24 bps
6261.42 bps
7250.77 bps
7264.03 bps
19895.93 bps
6244.38 bps
6862.85 bps
7288.81 bps
```

- com11 <- com25
- average 9898 bps
```
PS C:\250602_Works\250602_GitLab\ESP-Serial-Bridge\speed_test_script> python .\test1_receive_random_com11.py
8809.17 bps
7930.15 bps
12917.67 bps
7220.33 bps
12540.10 bps
7058.84 bps
7330.00 bps
17718.81 bps
7344.16 bps
6985.82 bps
6799.95 bps
7366.29 bps
16610.63 bps
7271.77 bps
7397.20 bps
7422.21 bps
17724.66 bps
7355.78 bps
6795.71 bps
7430.07 bps
19842.56 bps
```

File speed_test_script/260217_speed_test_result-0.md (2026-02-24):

# 260217 speed test result-0.md

## summary
各3ポート115200bpsで乱数を送る設定で、
Host x3→Client x3、各ポート600～45000 bps
Host x3←Client x3、各ポート7000～13000 bps

## log
PS C:\250602_Works\250602_GitLab\ESP-Serial-Bridge\speed_test_script> python .\test1_send_random_com3.py 

```
PS C:\250602_Works\250602_GitLab\ESP-Serial-Bridge\speed_test_script> python .\test1_receive_random_com24.py
18438.48 bps
7046.29 bps
14998.02 bps
11171.20 bps
8423.18 bps
6088.77 bps
14289.46 bps
14576.61 bps
41591.50 bps
10851.66 bps
35944.44 bps
43047.30 bps
20026.29 bps
17155.59 bps
23068.79 bps
27488.68 bps
34778.67 bps
35380.30 bps
42927.72 bps
5207.19 bps
10445.57 bps
51102.54 bps
40900.88 bps
29376.52 bps
37808.99 bps
34725.71 bps
33842.46 bps
1886.22 bps
22817.30 bps
6857.54 bps
42528.76 bps
9538.48 bps
15077.19 bps
37033.00 bps
41198.40 bps
5732.22 bps
18341.88 bps
16878.69 bps
24089.49 bps
40504.66 bps
13089.11 bps
6885.19 bps
15327.69 bps
17158.91 bps
23841.09 bps
29943.14 bps
44392.31 bps
31958.74 bps
8831.94 bps
9596.12 bps
8879.92 bps
10159.72 bps
16278.26 bps
14570.18 bps
10309.02 bps
1562.54 bps
10182.12 bps
693.48 bps
1863.45 bps
9416.21 bps
11106.05 bps
1822.02 bps
5685.66 bps
36568.68 bps
24094.63 bps
18866.83 bps
22560.98 bps
2049.90 bps
12749.07 bps
26033.16 bps
31136.82 bps
34049.18 bps
40418.31 bps
25735.79 bps
33861.97 bps
38974.56 bps
27327.49 bps
39183.08 bps
10093.79 bps
37144.24 bps
22968.86 bps
4860.04 bps
3689.12 bps
8440.19 bps
35191.58 bps
41239.16 bps
6713.72 bps
19615.23 bps
35368.83 bps
8548.06 bps
35747.21 bps
35170.27 bps
15427.37 bps
40580.89 bps
6941.64 bps
Traceback (most recent call last):
  File "C:\250602_Works\250602_GitLab\ESP-Serial-Bridge\speed_test_script\test1_receive_random_com24.py", line 14, in <module>
    data = ser.read(1024)
  File "C:\Users\YoshihiroNakagawa\AppData\Local\Programs\Python\Python313\Lib\site-packages\serial\serialwin32.py", line 288, in read       
    result_ok = win32.GetOverlappedResult(
        self._port_handle,
        ctypes.byref(self._overlapped_read),
        ctypes.byref(rc),
        True)
KeyboardInterrupt
PS C:\250602_Works\250602_GitLab\ESP-Serial-Bridge\speed_test_script>
```

PS C:\250602_Works\250602_GitLab\ESP-Serial-Bridge\speed_test_script> python .\test1_send_random_com6.py 
```
PS C:\250602_Works\250602_GitLab\ESP-Serial-Bridge\speed_test_script> python .\test1_receive_random_com25.py
3608.05 bps
16634.48 bps
6964.20 bps
15116.31 bps
14447.81 bps
49124.92 bps
17170.91 bps
24860.05 bps
41293.79 bps
27618.06 bps
18333.90 bps
17646.28 bps
20757.44 bps
28493.10 bps
36066.76 bps
41394.78 bps
12789.82 bps
9985.83 bps
41606.60 bps
29199.37 bps
26612.35 bps
30477.90 bps
35920.92 bps
38399.32 bps
9807.60 bps
2545.70 bps
28102.79 bps
3395.70 bps
41529.12 bps
9255.03 bps
15725.83 bps
34768.33 bps
41235.76 bps
5163.99 bps
29411.64 bps
14478.47 bps
37041.93 bps
14445.31 bps
11087.71 bps
12843.74 bps
16682.40 bps
26466.59 bps
18028.76 bps
33509.54 bps
30485.67 bps
16474.28 bps
12868.30 bps
7085.19 bps
9785.82 bps
5158.77 bps
3514.60 bps
10019.25 bps
1709.81 bps
8737.63 bps
4180.61 bps
1562.83 bps
15730.90 bps
2756.88 bps
11482.82 bps
2268.70 bps
2661.87 bps
35706.72 bps
19841.27 bps
25652.22 bps
23546.50 bps
1755.98 bps
22741.42 bps
39641.63 bps
29664.57 bps
37731.29 bps
42511.45 bps
19171.37 bps
38014.77 bps
49408.08 bps
26240.56 bps
44401.39 bps
3603.80 bps
35238.18 bps
19217.33 bps
5151.43 bps
3509.08 bps
3141.32 bps
42958.71 bps
41207.92 bps
16680.70 bps
13015.06 bps
33801.54 bps
14114.28 bps
25914.42 bps
43284.48 bps
5085.16 bps
```

PS C:\250602_Works\250602_GitLab\ESP-Serial-Bridge\speed_test_script> python .\test1_send_random_com11.py
```
PS C:\250602_Works\250602_GitLab\ESP-Serial-Bridge\speed_test_script> python .\test1_receive_random_com26.py
15857.36 bps
10815.55 bps
8371.26 bps
5944.79 bps
11133.65 bps
17935.29 bps
38607.58 bps
16756.47 bps
35914.60 bps
41303.26 bps
35082.89 bps
12612.27 bps
18397.46 bps
29716.19 bps
38256.72 bps
29591.31 bps
41386.07 bps
6872.46 bps
27073.61 bps
4159.11 bps
42313.41 bps
45472.52 bps
25492.54 bps
30666.91 bps
37233.10 bps
37184.62 bps
8720.30 bps
4140.51 bps
17469.84 bps
3730.49 bps
41754.83 bps
9231.85 bps
9290.59 bps
59889.66 bps
41453.69 bps
9041.79 bps
17376.19 bps
20114.69 bps
35642.15 bps
14564.71 bps
27550.65 bps
2780.25 bps
15251.15 bps
19051.05 bps
20969.00 bps
35228.54 bps
38883.97 bps
20580.78 bps
8697.07 bps
10882.13 bps
11897.34 bps
11625.58 bps
17784.51 bps
7932.75 bps
8228.15 bps
1637.52 bps
9084.25 bps
830.52 bps
3534.85 bps
1586.00 bps
10614.30 bps
2827.40 bps
16059.65 bps
2296.62 bps
2556.43 bps
34266.43 bps
19718.35 bps
18737.32 bps
24028.41 bps
3650.17 bps
18603.18 bps
33570.93 bps
37993.20 bps
36663.16 bps
45536.30 bps
26640.42 bps
32899.05 bps
43789.63 bps
27207.73 bps
35739.98 bps
3861.61 bps
44181.03 bps
21793.84 bps
8655.47 bps
6571.69 bps
7086.59 bps
2884.42 bps
38387.62 bps
18813.47 bps
16898.82 bps
39893.19 bps
16033.03 bps
25557.34 bps
16661.85 bps
```

PS C:\250602_Works\250602_GitLab\ESP-Serial-Bridge\speed_test_script> python .\test1_send_random_com24.py 

PS C:\250602_Works\250602_GitLab\ESP-Serial-Bridge\speed_test_script> python .\test1_receive_random_com3.py 
14669.03 bps
15661.48 bps
19257.90 bps
34876.60 bps
15286.43 bps
15410.23 bps
16248.38 bps
7791.71 bps
20527.65 bps
11691.29 bps
7389.27 bps
6266.90 bps
8060.07 bps
12979.58 bps
6615.63 bps
3437.97 bps
14200.15 bps
13377.67 bps
6181.14 bps
3699.86 bps
13922.97 bps
12545.38 bps
6850.23 bps
6340.55 bps
7959.66 bps
12520.17 bps
7204.28 bps
7148.66 bps
6590.51 bps
6467.96 bps
7640.82 bps
13570.47 bps
6387.90 bps
6987.18 bps
6694.92 bps
6725.29 bps
7570.47 bps
13577.24 bps
12281.96 bps
6544.59 bps
6890.15 bps
7804.24 bps
6382.55 bps
7111.57 bps
6783.89 bps
7305.08 bps
12229.71 bps
6597.65 bps
3716.93 bps
18343.96 bps
6741.65 bps
7327.07 bps
6926.89 bps
6998.46 bps
12595.52 bps
6389.69 bps
7662.57 bps
13014.65 bps
6144.32 bps
7359.22 bps
7584.18 bps
12298.30 bps
6992.35 bps
6911.21 bps
7150.58 bps
14670.52 bps
5564.98 bps
8467.26 bps
13857.12 bps
6795.72 bps
6606.32 bps
6826.43 bps
7117.28 bps
14238.91 bps
5873.73 bps
7944.53 bps
6844.91 bps
9889.39 bps
7011.30 bps
6235.78 bps
7622.52 bps
12558.52 bps
7351.78 bps
6951.60 bps
13772.55 bps
19834.26 bps
8729.37 bps
17811.78 bps
5333.63 bps
13487.42 bps
6955.94 bps
7391.08 bps
11155.46 bps
8067.38 bps
6897.81 bps
7351.09 bps
11743.86 bps
3651.72 bps
6236.70 bps
15138.36 bps
6773.23 bps
6643.21 bps
6760.79 bps
7326.70 bps
13117.82 bps
6275.93 bps
7601.98 bps
6495.59 bps
7312.12 bps
6018.77 bps
7950.81 bps
12610.50 bps
6946.18 bps
7208.70 bps
6509.75 bps
7055.15 bps
13861.49 bps
6801.47 bps
11647.10 bps
7564.08 bps
6855.40 bps
7337.36 bps
6173.69 bps
6794.24 bps
7312.04 bps
6501.55 bps
6354.63 bps
3713.12 bps
12641.42 bps
3647.35 bps
12861.16 bps
6227.98 bps
7698.21 bps
6555.30 bps
13047.16 bps
7870.41 bps
12543.04 bps
6698.80 bps
6207.74 bps

PS C:\250602_Works\250602_GitLab\ESP-Serial-Bridge\speed_test_script> python .\test1_send_random_com25.py

PS C:\250602_Works\250602_GitLab\ESP-Serial-Bridge\speed_test_script> python .\test1_receive_random_com6.py 
32623.65 bps
6543.21 bps
16819.17 bps
33493.77 bps
36696.06 bps
4026.19 bps
16514.15 bps
16534.51 bps
15839.52 bps
7898.33 bps
12473.38 bps
7224.74 bps
6623.15 bps
6751.67 bps
6567.28 bps
7117.74 bps
6509.31 bps
7418.94 bps
6640.19 bps
7185.92 bps
12867.94 bps
6885.92 bps
7094.84 bps
12737.19 bps
3599.01 bps
13128.23 bps
6431.20 bps
7071.45 bps
6823.90 bps
7211.80 bps
12424.09 bps
7635.47 bps
6700.63 bps
7331.95 bps
11862.81 bps
7864.58 bps
11034.91 bps
7129.67 bps
3726.81 bps
6646.86 bps
12316.09 bps
7768.36 bps
7242.53 bps
11911.28 bps
6731.92 bps
6539.02 bps
8101.78 bps
7142.69 bps
12376.85 bps
6965.36 bps
6407.34 bps
8063.39 bps
12600.14 bps
6815.78 bps
6631.64 bps
12355.35 bps
3820.30 bps
11382.84 bps
7375.71 bps
3654.48 bps
13020.48 bps
6835.18 bps
14053.98 bps
6031.12 bps
6163.03 bps
8671.91 bps
13011.82 bps
13315.37 bps
3440.84 bps
7233.23 bps
13671.43 bps
12363.75 bps
6993.44 bps
7216.38 bps
6616.05 bps
7199.03 bps
13310.06 bps
6336.50 bps
7273.40 bps
6678.67 bps
3637.17 bps
12491.73 bps
14528.18 bps
12779.55 bps
7010.74 bps
36059.33 bps
5409.38 bps
11893.50 bps
3243.29 bps
29024.93 bps
4799.97 bps
13548.68 bps
6908.28 bps
7277.12 bps
12611.14 bps
7817.24 bps
11340.84 bps
3801.88 bps
12591.33 bps
6695.37 bps
7424.93 bps
13325.29 bps
6712.58 bps
7211.53 bps
6276.22 bps
7053.50 bps
6697.27 bps
7049.59 bps
6698.97 bps
13042.46 bps
7407.51 bps
6977.62 bps
12591.64 bps
6545.12 bps
7045.85 bps
6562.75 bps
6816.28 bps
7986.85 bps
12715.29 bps
6709.05 bps
6612.01 bps
6375.54 bps
8190.90 bps
6910.28 bps
6048.35 bps
7453.78 bps
7139.39 bps
6790.07 bps
12977.12 bps
7319.35 bps
6084.09 bps
3465.69 bps
7675.17 bps
13709.74 bps
12450.13 bps
6165.95 bps
7055.90 bps
7553.36 bps
7580.09 bps
11397.82 bps
7603.78 bps

PS C:\250602_Works\250602_GitLab\ESP-Serial-Bridge\speed_test_script> python .\test1_send_random_com26.py 

PS C:\250602_Works\250602_GitLab\ESP-Serial-Bridge\speed_test_script> python .\test1_receive_random_com11.py                                 
10395.75 bps
17412.74 bps
36930.72 bps
15161.89 bps
13139.09 bps
16222.59 bps
13283.70 bps
13149.50 bps
19187.56 bps
7186.78 bps
6269.58 bps
3617.63 bps
6679.59 bps
13654.13 bps
6879.78 bps
6309.52 bps
7522.37 bps
6372.28 bps
7502.03 bps
11680.27 bps
6383.95 bps
3877.44 bps
15987.50 bps
7257.86 bps
8237.50 bps
12599.88 bps
7017.56 bps
7120.99 bps
7187.98 bps
12654.28 bps
6480.07 bps
6248.57 bps
3855.88 bps
13007.27 bps
6977.74 bps
12388.83 bps
6875.12 bps
7869.61 bps
6798.29 bps
6432.26 bps
6545.13 bps
7018.43 bps
7253.23 bps
13679.90 bps
12201.50 bps
7134.41 bps
6693.35 bps
6648.81 bps
6878.12 bps
7687.94 bps
12868.48 bps
7267.11 bps
6137.04 bps
3458.01 bps
7630.40 bps
13110.25 bps
6304.94 bps
7649.16 bps
17907.72 bps
7316.05 bps
6642.29 bps
6089.93 bps
8101.33 bps
6966.00 bps
12650.21 bps
7220.60 bps
6507.96 bps
16036.87 bps
6754.51 bps
12283.36 bps
6975.67 bps
7243.66 bps
6987.79 bps
6181.59 bps
7431.15 bps
6442.65 bps
6806.66 bps
7239.38 bps
11529.82 bps
3841.21 bps
13296.71 bps
6633.92 bps
18177.94 bps
7512.78 bps
10823.29 bps
6719.28 bps
8596.83 bps
14089.38 bps
9799.28 bps
6179.87 bps
8302.93 bps
10344.92 bps
10173.00 bps
13012.03 bps
7087.38 bps
12796.97 bps
6891.97 bps
7404.99 bps
12005.51 bps
13987.11 bps
6543.57 bps
3612.86 bps
6836.12 bps
12415.33 bps
7043.44 bps
7044.97 bps
7420.29 bps
7032.16 bps
12243.34 bps
6784.32 bps
5944.11 bps
7185.66 bps
8007.18 bps
6685.42 bps
7304.84 bps
12724.22 bps
6398.54 bps
7909.15 bps
12035.79 bps
6274.70 bps
3699.40 bps
7067.04 bps
12614.30 bps
6965.85 bps
6835.63 bps
3484.47 bps
6927.07 bps
13013.27 bps
6253.18 bps
7563.83 bps
6354.09 bps
3717.84 bps
13456.84 bps
11117.38 bps
8250.52 bps
6718.96 bps

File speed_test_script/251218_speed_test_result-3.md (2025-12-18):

# 251218_speed_test_result-3.md

## result3
- Host -> Client: around 13000 bps, たまに7000 pbs
- Client -> Host: around 100000 bps, 安定

### test3-1
- Host -> Client: around 13000 bps, たまに7000 pbs
```
PS C:\250602_Works\250602_GitLab\ESP-Serial-Bridge\speed_test_script> python .\test1_receive_random.py
2329.42 bps
16523.34 bps
13072.70 bps
14283.74 bps
13004.31 bps
13610.43 bps
15456.41 bps
12438.58 bps
7194.69 bps
14002.30 bps
12974.87 bps
13865.76 bps
13491.13 bps
6765.28 bps
13316.72 bps
7418.59 bps
```

### test3-2
- Client -> Host: around 100000 bps, 安定
```
PS C:\250602_Works\250602_GitLab\ESP-Serial-Bridge\speed_test_script> python .\test1_receive_random.py
2272.60 bps
100997.60 bps
101210.61 bps
100990.90 bps
101178.83 bps
100955.79 bps
101211.82 bps
101224.42 bps
101149.83 bps
101099.87 bps
101183.12 bps
101104.42 bps
101218.29 bps
101217.81 bps
101093.97 bps
101109.94 bps
101140.87 bps
101307.08 bps
```

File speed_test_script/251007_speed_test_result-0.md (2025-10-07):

# 251007_speed_test_result-0.md

## test1
- Host -> Client: around 11000 bps, 1/10
- Client -> Host: around 80000 bps

### test1 detail
- Host -> Client: around 11000 bps, 1/10
```
PS C:\250602_Works\250602_GitLab\ESP-Serial-Bridge\speed_test_script> python .\test1_receive_random.py
9437.34 bps
10642.07 bps
6163.63 bps
14873.13 bps
11102.08 bps
11005.70 bps
5552.57 bps
10833.07 bps
11031.34 bps
5211.61 bps
5783.82 bps
16435.98 bps
10812.21 bps
9828.91 bps
12238.48 bps
5398.71 bps
11187.61 bps
```
- Client -> Host: around 80000 bps
```
PS C:\250602_Works\250602_GitLab\ESP-Serial-Bridge\speed_test_script> python .\test1_receive_random.py
76537.87 bps
80721.85 bps
80845.42 bps
80787.46 bps
81025.16 bps
80693.60 bps
80843.86 bps
80668.67 bps
80694.41 bps
80951.30 bps
80942.55 bps
80923.27 bps
80717.47 bps
```

## test2
- Host -> Client, around 11000 bps, 1/10
- Client -> Host, around 115200 bps, Ok

### test2, detail
- Host -> Client, around 11000 bps, 1/10
```
PS C:\250602_Works\250602_GitLab\ESP-Serial-Bridge\speed_test_script> python .\test1_receive_random.py
8613.45 bps
7017.59 bps
13569.80 bps
6700.04 bps
13826.51 bps
14297.73 bps
13348.43 bps
13311.04 bps
13815.43 bps
6572.14 bps
```
- Client -> Host, around 115200 bps, Ok
```
PS C:\250602_Works\250602_GitLab\ESP-Serial-Bridge\speed_test_script> python .\test1_receive_random.py
2490.32 bps
103051.81 bps
101330.02 bps
101190.01 bps
101395.86 bps
101285.53 bps
101177.61 bps
101078.65 bps
101285.08 bps
100570.91 bps
100694.02 bps
```

## test3
- Host -> Client, around 13000 bps, 1/10
- Client -> Host, around 115200 bps

### test3, detail
- Host -> Client, around 13000 bps, 1/10
```
PS C:\250602_Works\250602_GitLab\ESP-Serial-Bridge\speed_test_script> python .\test1_receive_random.py
8643.42 bps
13705.61 bps
7663.88 bps
13088.96 bps
12960.40 bps
13315.06 bps
14086.15 bps
13497.89 bps
14034.07 bps
13409.55 bps
```

- Client -> Host, around 115200 bps
```
PS C:\250602_Works\250602_GitLab\ESP-Serial-Bridge\speed_test_script> python .\test1_receive_random.py
825.76 bps
101699.98 bps
101086.60 bps
100784.28 bps
101176.80 bps
101184.19 bps
101181.45 bps
100977.22 bps
101200.93 bps
101220.15 bps
```

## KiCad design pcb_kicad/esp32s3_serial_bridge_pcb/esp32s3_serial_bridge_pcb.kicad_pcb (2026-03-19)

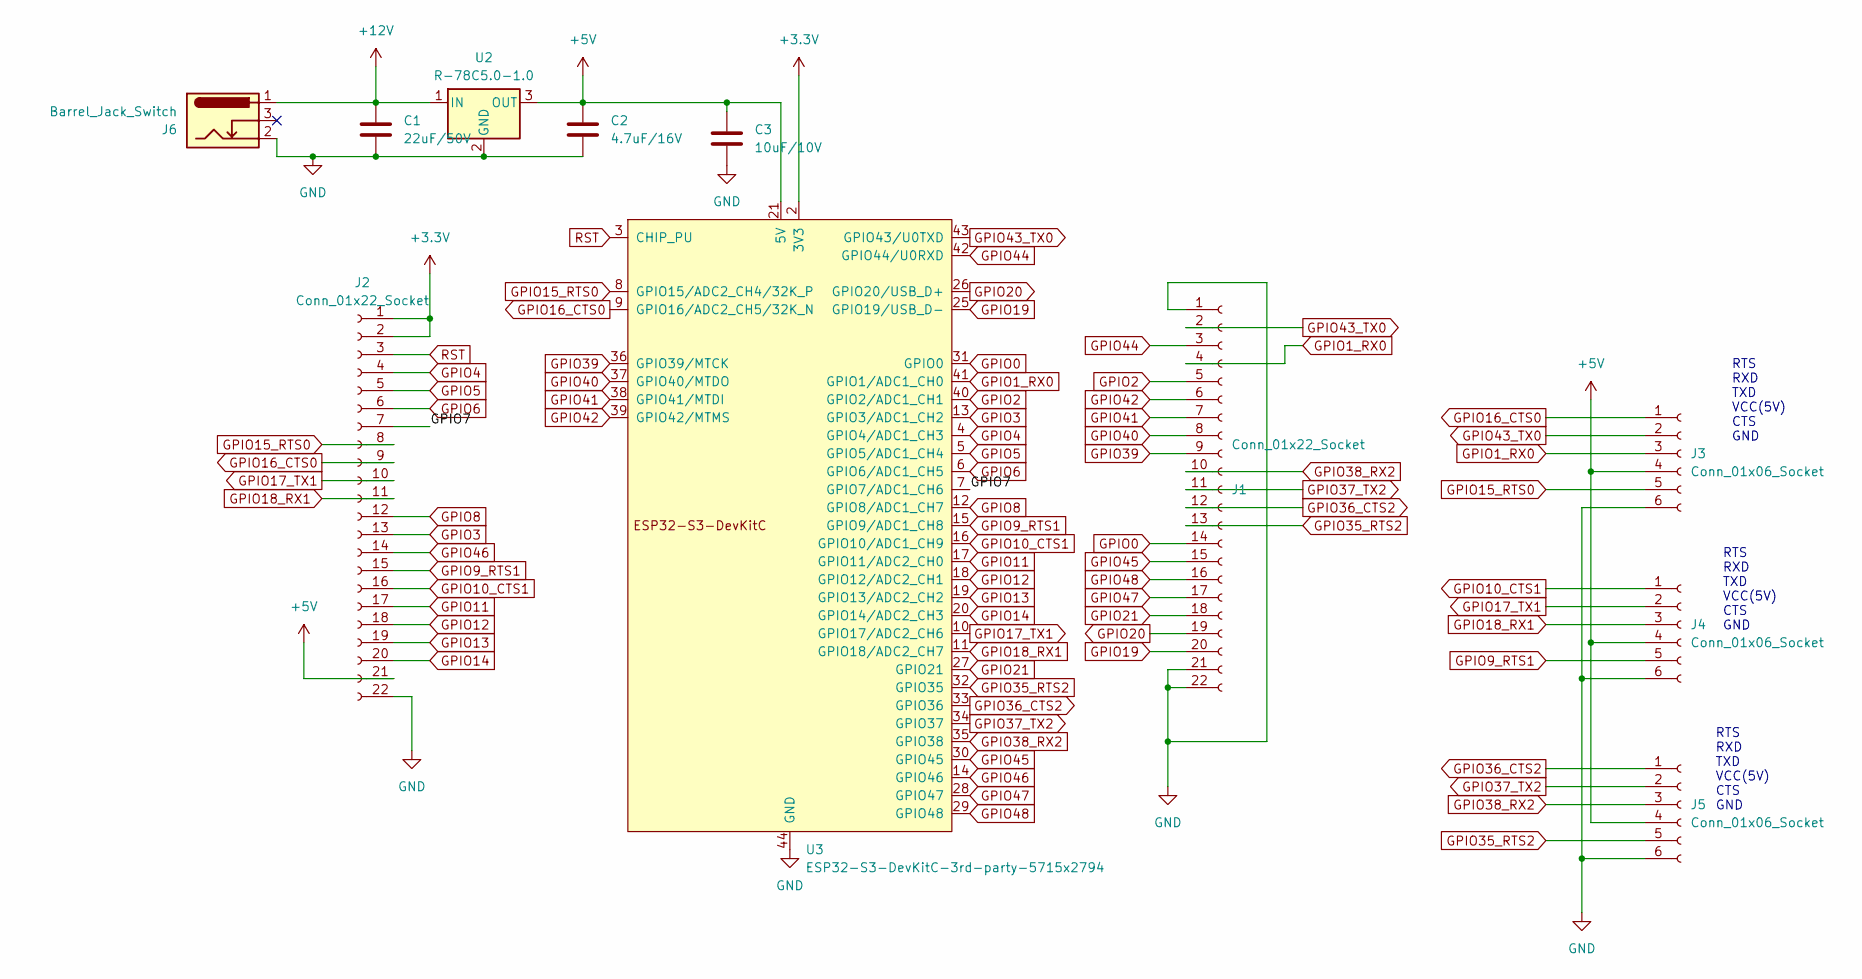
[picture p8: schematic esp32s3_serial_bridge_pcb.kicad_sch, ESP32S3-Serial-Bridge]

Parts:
C1: 22uF/50V; C_2220_5750Metric_Pad1.97x5.40mm_HandSolder
C2: 4.7uF/16V; C_1210_3225Metric_Pad1.33x2.70mm_HandSolder
C3: 10uF/10V; C_1210_3225Metric_Pad1.33x2.70mm_HandSolder
J1, J2: Conn_01x22_Socket; PinHeader_1x22_P2.54mm_Vertical
J3, J4, J5: Conn_01x06_Socket; PinHeader_1x06_P2.54mm_Vertical
J6: Barrel_Jack_Switch; BarrelJack_Horizontal
U2: R-78C5.0-1.0; Converter_DCDC_RECOM_R-78E-0.5_THT
U3: ESP32-S3-DevKitC-3rd-party-5715x2794; ESP32-S3-DevKitC_3rd_party_5715x2794

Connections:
+3.3V: J2.1, J2.2, U3.1 (3V3), U3.2 (3V3)
+5V: C2.1, C3.1, J2.21, J3.4, J4.4, J5.4, U2.3 (OUT), U3.21 (5V)
+12V: C1.1, J6.1, U2.1 (IN)
/GPIO7: J2.7, U3.7 (GPIO7/ADC1_CH6)
GND: C1.2, C2.2, C3.2, J1.1, J1.21, J1.22, J2.22, J3.6, J4.6, J5.6, J6.2, U2.2 (GND), U3.22 (GND), U3.23 (GND), U3.24 (GND), U3.44 (GND)
GPIO0: J1.14, U3.31 (GPIO0)
GPIO1_RX0: J1.4, J3.3, U3.41 (GPIO1/ADC1_CH0)
GPIO2: J1.5, U3.40 (GPIO2/ADC1_CH1)
GPIO3: J2.13, U3.13 (GPIO3/ADC1_CH2)
GPIO4: J2.4, U3.4 (GPIO4/ADC1_CH3)
GPIO5: J2.5, U3.5 (GPIO5/ADC1_CH4)
GPIO6: J2.6, U3.6 (GPIO6/ADC1_CH5)
GPIO8: J2.12, U3.12 (GPIO8/ADC1_CH7)
GPIO9_RTS1: J2.15, J4.5, U3.15 (GPIO9/ADC1_CH8)
GPIO10_CTS1: J2.16, J4.1, U3.16 (GPIO10/ADC1_CH9)
GPIO11: J2.17, U3.17 (GPIO11/ADC2_CH0)
GPIO12: J2.18, U3.18 (GPIO12/ADC2_CH1)
GPIO13: J2.19, U3.19 (GPIO13/ADC2_CH2)
GPIO14: J2.20, U3.20 (GPIO14/ADC2_CH3)
GPIO15_RTS0: J2.8, J3.5, U3.8 (GPIO15/ADC2_CH4/32K_P)
GPIO16_CTS0: J2.9, J3.1, U3.9 (GPIO16/ADC2_CH5/32K_N)
GPIO17_TX1: J2.10, J4.2, U3.10 (GPIO17/ADC2_CH6)
GPIO18_RX1: J2.11, J4.3, U3.11 (GPIO18/ADC2_CH7)
GPIO19: J1.20, U3.25 (GPIO19/USB_D-)
GPIO20: J1.19, U3.26 (GPIO20/USB_D+)
GPIO21: J1.18, U3.27 (GPIO21)
GPIO35_RTS2: J1.13, J5.5, U3.32 (GPIO35)
GPIO36_CTS2: J1.12, J5.1, U3.33 (GPIO36)
GPIO37_TX2: J1.11, J5.2, U3.34 (GPIO37)
GPIO38_RX2: J1.10, J5.3, U3.35 (GPIO38)
GPIO39: J1.9, U3.36 (GPIO39/MTCK)
GPIO40: J1.8, U3.37 (GPIO40/MTDO)
GPIO41: J1.7, U3.38 (GPIO41/MTDI)
GPIO42: J1.6, U3.39 (GPIO42/MTMS)
GPIO43_TX0: J1.2, J3.2, U3.43 (GPIO43/U0TXD)
GPIO44: J1.3, U3.42 (GPIO44/U0RXD)
GPIO45: J1.15, U3.30 (GPIO45)
GPIO46: J2.14, U3.14 (GPIO46)
GPIO47: J1.17, U3.28 (GPIO47)
GPIO48: J1.16, U3.29 (GPIO48)
RST: J2.3, U3.3 (CHIP_PU)

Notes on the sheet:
RTS RXD TXD VCC(5V) CTS GND

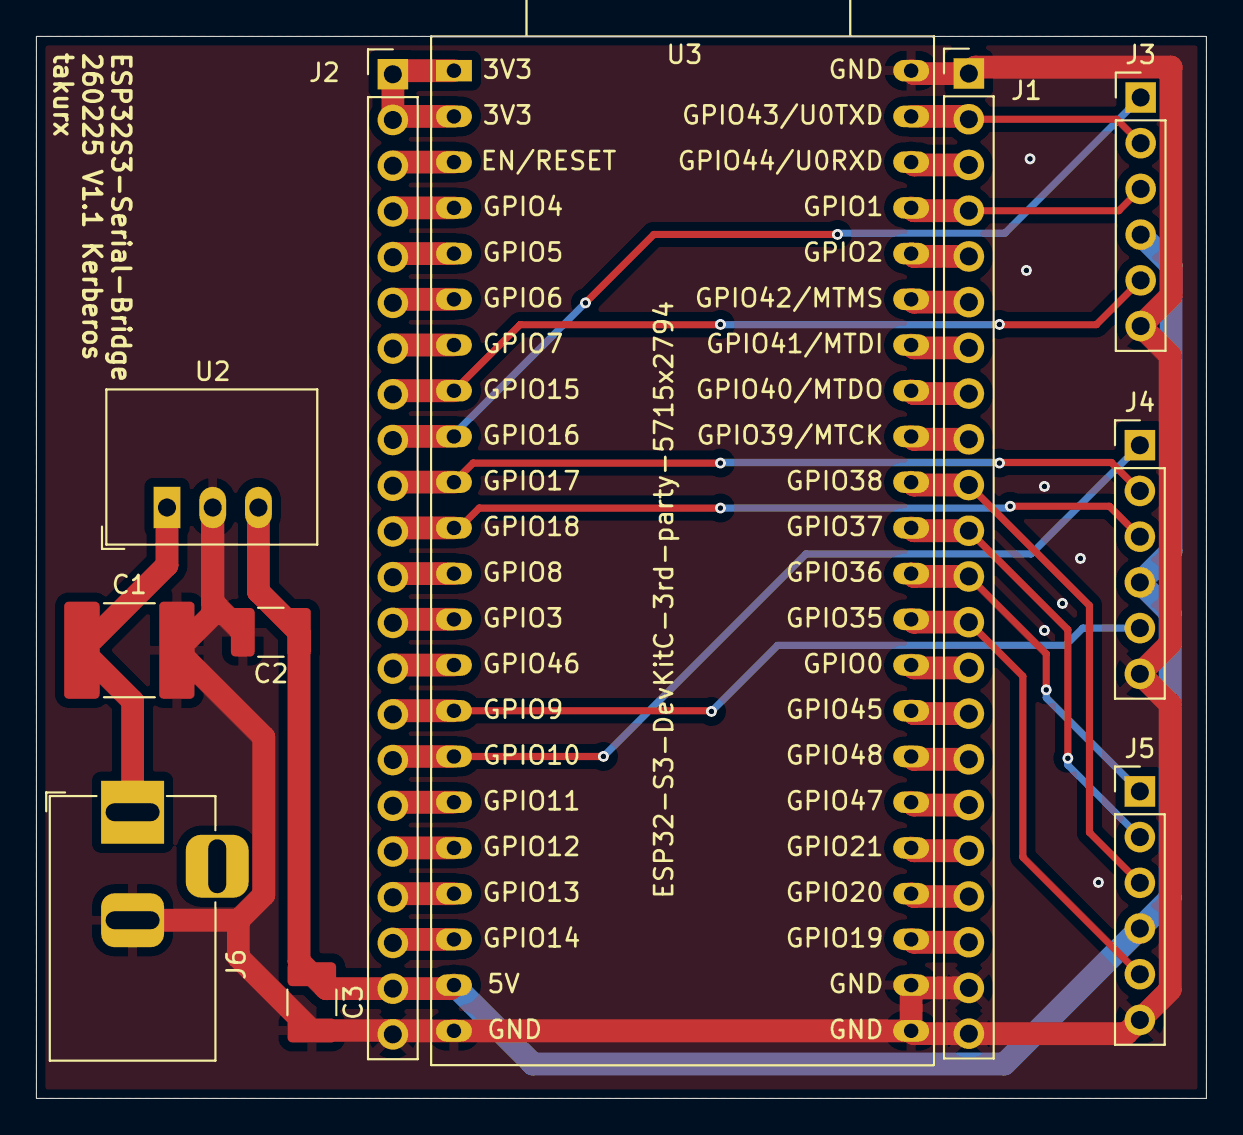
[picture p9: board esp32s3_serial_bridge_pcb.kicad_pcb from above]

Board: 2 copper layers, 65.0 x 59.0 mm, 11 parts (0 on the bottom side), 41 nets.

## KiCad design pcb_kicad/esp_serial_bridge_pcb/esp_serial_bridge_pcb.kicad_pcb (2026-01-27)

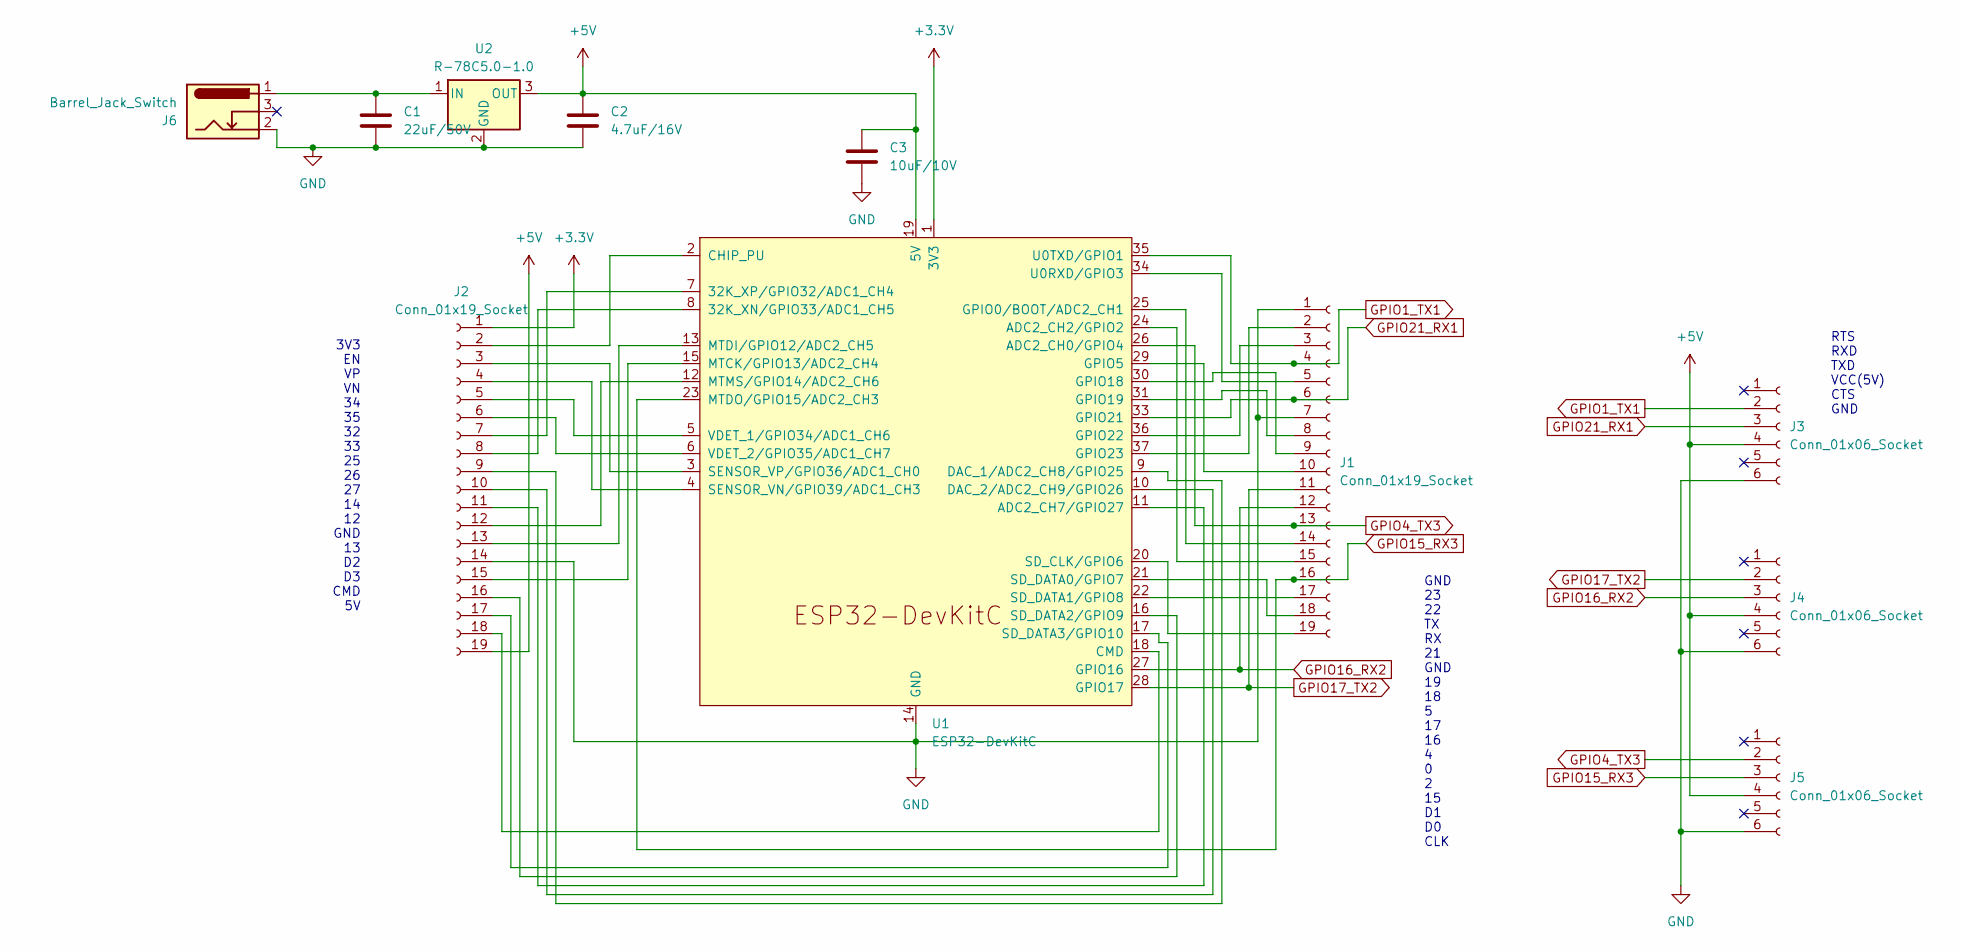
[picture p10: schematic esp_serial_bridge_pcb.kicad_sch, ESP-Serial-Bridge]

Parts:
C1: 22uF/50V; C_2220_5750Metric_Pad1.97x5.40mm_HandSolder
C2: 4.7uF/16V; C_1210_3225Metric_Pad1.33x2.70mm_HandSolder
C3: 10uF/10V; C_1210_3225Metric_Pad1.33x2.70mm_HandSolder
J1, J2: Conn_01x19_Socket; PinHeader_1x19_P2.54mm_Vertical
J3, J4, J5: Conn_01x06_Socket; PinHeader_1x06_P2.54mm_Vertical
J6: Barrel_Jack_Switch; BarrelJack_Horizontal
U1: ESP32-DevKitC
U2: R-78C5.0-1.0; Converter_DCDC_RECOM_R-78E-0.5_THT

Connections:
+3.3V: J2.1, U1.1 (3V3)
+5V: C2.1, C3.1, J2.19, J3.4, J4.4, J5.4, U1.19 (5V), U2.3 (OUT)
GND: C1.2, C2.2, C3.2, J1.1, J1.7, J2.14, J3.6, J4.6, J5.6, J6.2, U1.14 (GND), U1.32 (GND), U1.38 (GND), U2.2 (GND)
GPIO1_TX1: J1.4, J3.2, U1.35 (U0TXD/GPIO1)
GPIO4_TX3: J1.13, J5.2, U1.26 (ADC2_CH0/GPIO4)
GPIO15_RX3: J1.16, J5.3, U1.23 (MTDO/GPIO15/ADC2_CH3)
GPIO16_RX2: J1.12, J4.3, U1.27 (GPIO16)
GPIO17_TX2: J1.11, J4.2, U1.28 (GPIO17)
GPIO21_RX1: J1.6, J3.3, U1.33 (GPIO21)
unnamed: J1.2, U1.37 (GPIO23)
unnamed: J1.3, U1.36 (GPIO22)
unnamed: J1.5, U1.34 (U0RXD/GPIO3)
unnamed: J1.8, U1.31 (GPIO19)
unnamed: J1.9, U1.30 (GPIO18)
unnamed: J1.10, U1.29 (GPIO5)
unnamed: J1.14, U1.25 (GPIO0/BOOT/ADC2_CH1)
unnamed: J1.15, U1.24 (ADC2_CH2/GPIO2)
unnamed: J1.17, U1.22 (SD_DATA1/GPIO8)
unnamed: J1.18, U1.21 (SD_DATA0/GPIO7)
unnamed: J1.19, U1.20 (SD_CLK/GPIO6)
unnamed: J2.2, U1.2 (CHIP_PU)
unnamed: J2.3, U1.3 (SENSOR_VP/GPIO36/ADC1_CH0)
unnamed: J2.4, U1.4 (SENSOR_VN/GPIO39/ADC1_CH3)
unnamed: J2.5, U1.5 (VDET_1/GPIO34/ADC1_CH6)
unnamed: J2.6, U1.6 (VDET_2/GPIO35/ADC1_CH7)
unnamed: J2.7, U1.7 (32K_XP/GPIO32/ADC1_CH4)
unnamed: J2.8, U1.8 (32K_XN/GPIO33/ADC1_CH5)
unnamed: J2.9, U1.9 (DAC_1/ADC2_CH8/GPIO25)
unnamed: J2.10, U1.10 (DAC_2/ADC2_CH9/GPIO26)
unnamed: J2.11, U1.11 (ADC2_CH7/GPIO27)
unnamed: J2.12, U1.12 (MTMS/GPIO14/ADC2_CH6)
unnamed: J2.13, U1.13 (MTDI/GPIO12/ADC2_CH5)
unnamed: J2.15, U1.15 (MTCK/GPIO13/ADC2_CH4)
unnamed: J2.16, U1.16 (SD_DATA2/GPIO9)
unnamed: J2.17, U1.17 (SD_DATA3/GPIO10)
unnamed: J2.18, U1.18 (CMD)
unnamed: C1.1, J6.1, U2.1 (IN)

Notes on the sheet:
GND 23 22 TX RX 21 GND 19 18 5 17 16 4 0 2 15 D1 D0 CLK
3V3 EN VP VN 34 35 32 33 25 26 27 14 12 GND 13 D2 D3 CMD 5V
RTS RXD TXD VCC(5V) CTS GND

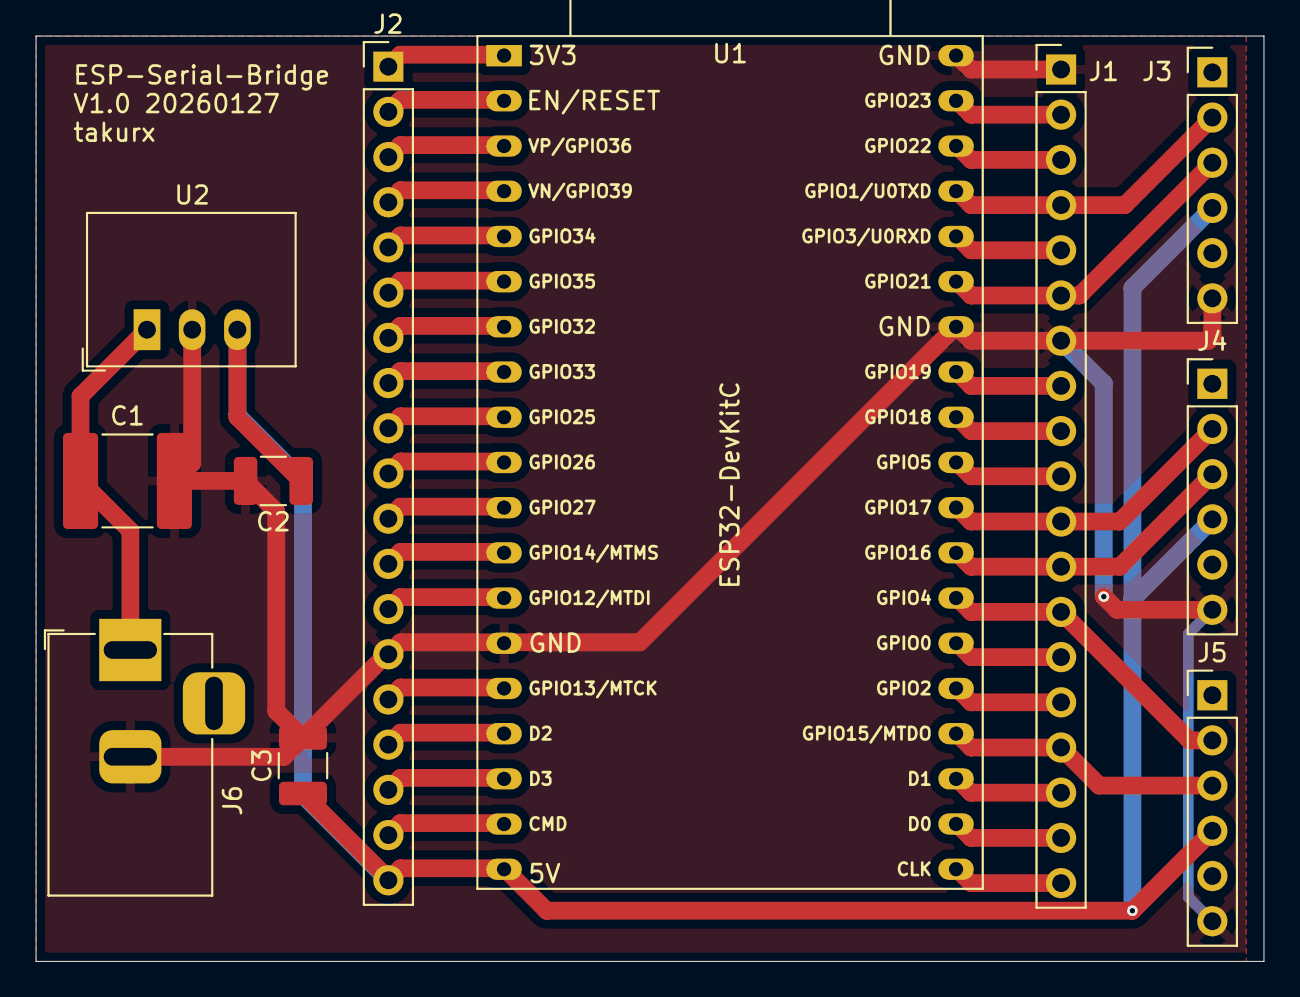
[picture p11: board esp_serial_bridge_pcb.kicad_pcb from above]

Board: 2 copper layers, 69.0 x 52.0 mm, 11 parts (0 on the bottom side), 37 nets.

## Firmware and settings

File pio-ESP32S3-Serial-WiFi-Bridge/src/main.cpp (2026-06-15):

/*********************************************************************************
 * pio-ESP32S3-Serial-WiFi-Bridge
 *
 * Simple WiFi Serial Bridge for Espressif microcontrollers
 *
 * Forked from https://github.com/AlphaLima/ESP32-Serial-Bridge
 *
 * Added compatibility for ESP8266, WiFi reconnect on failure, and mDNS
 *discovery.
 *
 * Note: ESP8266 is limited to 115200 baud and may be somewhat unreliable in
 *       this application.
 *
 *   -- Yuri - Aug 2021
 *
 * Fixed compatibility with Arduino framework 2.0 -- Yuri - Apr 2023
 * Implemented UDP + bug fixes                    -- Yuri - Apr 2023
 *
 * Disclaimer: Don't use for life support systems or any other situation
 * where system failure may affect user or environmental safety.
 *********************************************************************************/

#include <Arduino.h>

#define ESP32 1

#ifdef ESP32
#include <ESPmDNS.h>
#include <WiFi.h>
#include <esp_wifi.h>
#elif defined(ESP8266)
#include <ESP8266WiFi.h>
#include <ESP8266mDNS.h>
#include <SoftwareSerial.h>  // use SoftwareSerial for ESP8266
#endif

#include "config.h"

#ifdef OTA_HANDLER
#include <ArduinoOTA.h>
#endif

#ifdef ESP32

#ifdef PROTOCOL_UDP
#include <AsyncUDP.h>

AsyncUDP udp0, udp1, udp2;
AsyncUDP *udp[NUM_COM] = {&udp0, &udp1, &udp2};
uint16_t udp_port[NUM_COM] = {SERIAL0_UDP_PORT, SERIAL1_UDP_PORT,
                              SERIAL2_UDP_PORT};
#endif

#ifdef BLUETOOTH  // inside the ESP32 condition, since ESP8266 doesn't have BT
#include <BluetoothSerial.h>
BluetoothSerial SerialBT;
#endif

HardwareSerial Serial_one(1);
HardwareSerial Serial_two(2);
HardwareSerial* COM[NUM_COM] = {&Serial, &Serial_one, &Serial_two};
//HardwareSerial* COM[NUM_COM] = {&Serial};
#elif defined(ESP8266)
SoftwareSerial Serial_zero(SERIAL0_RXPIN, SERIAL0_TXPIN);
SoftwareSerial Serial_one(SERIAL1_RXPIN, SERIAL1_TXPIN);
SoftwareSerial* COM[NUM_COM] = {&Serial_zero, &Serial_one};
#endif

#ifdef PROTOCOL_TCP
#include <WiFiClient.h>
WiFiServer server_0(SERIAL0_TCP_PORT);
WiFiServer server_1(SERIAL1_TCP_PORT);

#ifdef ESP32
WiFiServer server_2(SERIAL2_TCP_PORT);
WiFiServer* server[NUM_COM] = {&server_0, &server_1, &server_2};
//WiFiServer* server[NUM_COM] = {&server_0};
#elif defined(ESP8266)
WiFiServer* server[NUM_COM] = {&server_0, &server_1};
#endif
WiFiClient TCPClient[NUM_COM][MAX_NMEA_CLIENTS];
#endif

uint8_t buf1[NUM_COM][SOFTWAREBUFFERSIZE];
uint8_t buf2[NUM_COM][SOFTWAREBUFFERSIZE];
uint8_t txPending[NUM_COM][SOFTWAREBUFFERSIZE];
size_t txPendingLen[NUM_COM] = {0};

#ifdef ESP32
uint16_t i1[NUM_COM] = {0, 0, 0};
//uint16_t i1[NUM_COM] = {0};
#elif defined(ESP8266)
uint16_t i1[NUM_COM] = {0, 0};
#endif

uint8_t BTbuf[SOFTWAREBUFFERSIZE];
uint16_t iBT = 0;

#ifdef MODE_STA
#if defined(ESP32)
void WiFiStationDisconnected(WiFiEvent_t event, WiFiEventInfo_t info) {
#endif
#if defined(ESP8266)
    WiFiEventHandler stationDisconnectedHandler;
    void WiFiStationDisconnected(
        const WiFiEventSoftAPModeStationDisconnected& evt) {
#endif
        debug.print("WiFi disconnected: ");
#ifdef ESP32
        debug.println(info.wifi_sta_disconnected.reason);
#endif
        debug.println("Trying to reconnect..");
        WiFi.begin(SSID, PASSWD);
        while (WiFi.status() != WL_CONNECTED) {
            delay(500);
            debug.print(".");
        }
        debug.println("connected");
        debug.print("IP address: ");
        debug.println(WiFi.localIP());
    }
#endif

    void setup() {
        delay(500);

#ifdef ESP32
        // Flow control disable
        COM[0]->setRxBufferSize(HARDWAREBUFFERSIZE);
        COM[0]->setTxBufferSize(HARDWAREBUFFERSIZE);
        COM[0]->begin(UART_BAUD0, SERIAL_PARAM0, SERIAL0_RXPIN, SERIAL0_TXPIN);
        COM[0]->setHwFlowCtrlMode(UART_HW_FLOWCTRL_DISABLE);
        pinMode(SERIAL0_CTSPIN, OUTPUT);
        pinMode(SERIAL0_RTSPIN, OUTPUT);
        digitalWrite(SERIAL0_CTSPIN, LOW);
        digitalWrite(SERIAL0_RTSPIN, LOW);

        COM[1]->setRxBufferSize(HARDWAREBUFFERSIZE);
        COM[1]->setTxBufferSize(HARDWAREBUFFERSIZE);
        COM[1]->begin(UART_BAUD1, SERIAL_PARAM1, SERIAL1_RXPIN, SERIAL1_TXPIN);
        COM[1]->setHwFlowCtrlMode(UART_HW_FLOWCTRL_DISABLE);
        pinMode(SERIAL1_CTSPIN, OUTPUT);
        pinMode(SERIAL1_RTSPIN, OUTPUT);
        digitalWrite(SERIAL1_CTSPIN, LOW);
        digitalWrite(SERIAL1_RTSPIN, LOW);
        
        COM[2]->setRxBufferSize(HARDWAREBUFFERSIZE);
        COM[2]->setTxBufferSize(HARDWAREBUFFERSIZE);
        COM[2]->begin(UART_BAUD2, SERIAL_PARAM2, SERIAL2_RXPIN, SERIAL2_TXPIN);
        COM[2]->setHwFlowCtrlMode(UART_HW_FLOWCTRL_DISABLE);
        pinMode(SERIAL2_CTSPIN, OUTPUT);
        pinMode(SERIAL2_RTSPIN, OUTPUT);
        digitalWrite(SERIAL2_CTSPIN, LOW);
        digitalWrite(SERIAL2_RTSPIN, LOW);

        /* //Flow control enable
        COM[0]->begin(UART_BAUD0, SERIAL_PARAM0, SERIAL0_RXPIN, SERIAL0_TXPIN);
        COM[0]->setPins(SERIAL0_RXPIN, SERIAL0_TXPIN, SERIAL0_CTSPIN, SERIAL0_RTSPIN);
        COM[0]->setHwFlowCtrlMode(UART_HW_FLOWCTRL_CTS_RTS);
        
        COM[1]->begin(UART_BAUD1, SERIAL_PARAM1, SERIAL1_RXPIN, SERIAL1_TXPIN);
        COM[1]->setPins(SERIAL1_RXPIN, SERIAL1_TXPIN, SERIAL1_CTSPIN, SERIAL1_RTSPIN);
        COM[1]->setHwFlowCtrlMode(UART_HW_FLOWCTRL_CTS_RTS);
        
        COM[2]->begin(UART_BAUD2, SERIAL_PARAM2, SERIAL2_RXPIN, SERIAL2_TXPIN);
        COM[2]->setPins(SERIAL2_RXPIN, SERIAL2_TXPIN, SERIAL2_CTSPIN, SERIAL2_RTSPIN);
        COM[2]->setHwFlowCtrlMode(UART_HW_FLOWCTRL_CTS_RTS);
        */
#elif defined(ESP8266)
    COM[0]->begin(UART_BAUD0);
    COM[1]->begin(UART_BAUD1);
    debug.begin(UART_BAUD0);
#endif
        Serial.println("\n\nSerial Bridge Starting...");
        debug.print("\n\nWiFi serial bridge ");
        debug.println(VERSION);

#ifdef MODE_AP
        debug.println("Open ESP Access Point Mode");
        WiFi.mode(WIFI_AP);
        WiFi.softAP(SSID, PASSWD);  // configure SSID and password for softAP
        delay(2000);            // VERY IMPORTANT
        WiFi.softAPConfig(STATIC_IP, STATIC_IP,
                          NETMASK);  // configure ip address for softAP
#endif

#ifdef MODE_STA
        debug.println("Open ESP Station Mode");
        WiFi.mode(WIFI_STA);
#ifdef ESP32
        WiFi.onEvent(WiFiStationDisconnected,
                     ARDUINO_EVENT_WIFI_STA_DISCONNECTED);
#elif defined(ESP8266)
    stationDisconnectedHandler =
        WiFi.onSoftAPModeStationDisconnected(&WiFiStationDisconnected);
#endif
        WiFi.begin(SSID, PASSWD);
        debug.print("Connecting to: ");
        debug.print(SSID);
        debug.print("..");
        while (WiFi.status() != WL_CONNECTED) {
            delay(500);
            debug.print(".");
        }
        debug.println("connected");
        debug.print("IP address: ");
        debug.println(WiFi.localIP());

        if (!MDNS.begin(HOSTNAME)) {
            debug.println("Error starting mDNS");
        } else {
            debug.print("Started mDNS, discoverable as: ");
            debug.println(HOSTNAME);
            MDNS.addService("_telnet", "_tcp", SERIAL0_TCP_PORT);
        }
#endif

#ifdef OTA_HANDLER
        ArduinoOTA.onStart([]() {
            String type;
            if (ArduinoOTA.getCommand() == U_FLASH)
                type = "sketch";
            else  // U_SPIFFS
                type = "filesystem";

            // NOTE: if updating SPIFFS this would be the place to unmount
            // SPIFFS using SPIFFS.end()
            Serial.println("Start updating " + type);
        });
        ArduinoOTA.onEnd([]() { Serial.println("\nEnd"); });
        ArduinoOTA.onProgress([](unsigned int progress, unsigned int total) {
            Serial.printf("Progress: %u%%\r", (progress / (total / 100)));
        });
        ArduinoOTA.onError([](ota_error_t error) {
            Serial.printf("Error[%u]: ", error);
            if (error == OTA_AUTH_ERROR)
                Serial.println("Auth Failed");
            else if (error == OTA_BEGIN_ERROR)
                Serial.println("Begin Failed");
            else if (error == OTA_CONNECT_ERROR)
                Serial.println("Connect Failed");
            else if (error == OTA_RECEIVE_ERROR)
                Serial.println("Receive Failed");
            else if (error == OTA_END_ERROR)
                Serial.println("End Failed");
        });
        // if DNSServer is started with "*" for domain name, it will reply with
        // provided IP to all DNS request

        ArduinoOTA.begin();
#endif

#ifdef PROTOCOL_TCP
        for (int num = 0; num < NUM_COM; num++) {
            debug.print("Starting TCP Server ");
            debug.println(num + 1);
            server[num]->begin();  // start TCP server
            server[num]->setNoDelay(true);
        }
#endif

#ifdef ESP32
#ifdef PROTOCOL_UDP
        for (uint16_t num = 0; num < NUM_COM; num++) {
            if (udp[num]->listen(udp_port[num])) {
                debug.printf("Listening on UDP port %d\n", udp_port[num]);
                udp[num]->onPacket([num](AsyncUDPPacket packet) {
                    COM[num]->write(packet.data(), packet.length()); });
                    }
                }
#endif
#ifdef BLUETOOTH
        debug.printf("Bluetooth discoverable at %s\n", SSID);
        SerialBT.begin(SSID);  // Bluetooth device name
#endif
#endif

#ifdef BATTERY_SAVER
#ifdef ESP32
        esp_err_t esp_wifi_set_max_tx_power(50);  // lower WiFi Power
#elif defined(ESP8266)
    WiFi.setOutputPower(15);
#endif
#endif
    }

    void loop() {
#ifdef OTA_HANDLER
        ArduinoOTA.handle();
#endif

#ifdef ESP32
#ifdef BLUETOOTH
        if (SerialBT.hasClient()) {
            while (SerialBT.available()) {
                BTbuf[iBT] = SerialBT.read();
                iBT++;
                if (iBT == SOFTWAREBUFFERSIZE - 1) break;
            }
            COM[BLUETOOTH]->write(BTbuf, iBT);
            iBT = 0;
        }
#endif
#endif

#ifdef PROTOCOL_TCP
        for (int num = 0; num < NUM_COM; num++) {
            if (server[num]->hasClient()) {
                for (byte i = 0; i < MAX_NMEA_CLIENTS; i++) {
                    // find free/disconnected spot
                    if (!TCPClient[num][i] || !TCPClient[num][i].connected()) {
                        if (TCPClient[num][i]) TCPClient[num][i].stop();
                        while (COM[num]->available()) COM[num]->read();  // flush serial buffer for new clients
                        TCPClient[num][i] = server[num]->available();
                        debug.print("New client for COM");
                        debug.print(num);
                        debug.print(" #");
                        debug.println(i);
                        continue;
                    }
                }
                // no free/disconnected spot so reject
                WiFiClient TmpserverClient = server[num]->available();
                TmpserverClient.stop();
            }
        }
#endif

        for (int num = 0; num < NUM_COM; num++) {
            if (COM[num] != NULL) {
#ifdef PROTOCOL_TCP
                if (txPendingLen[num] > 0) {
                    size_t writable = COM[num]->availableForWrite();
                    if (writable > 0) {
                        size_t toSend = min(writable, txPendingLen[num]);
                        size_t sent = COM[num]->write(txPending[num], toSend);
                        if (sent > 0) {
                            txPendingLen[num] -= sent;
                            if (txPendingLen[num] > 0) {
                                memmove(txPending[num], txPending[num] + sent,
                                        txPendingLen[num]);
                            }
                        }
                    }
                }

                for (byte cln = 0; cln < MAX_NMEA_CLIENTS; cln++) {
                    if (TCPClient[num][cln]) {
                        int avail = TCPClient[num][cln].available();
                        if (avail > 0) {
                            i1[num] = TCPClient[num][cln].readBytes(
                                buf1[num],
                                min(avail, SOFTWAREBUFFERSIZE - 1));  // bulk read from TCP client
                            size_t offset = 0;
                            size_t writable = COM[num]->availableForWrite();
                            if (writable > 0) {
                                size_t immediate = min(static_cast<size_t>(i1[num]), writable);
                                size_t sent = COM[num]->write(buf1[num], immediate);
                                offset = sent;
                            }

                            if (offset < i1[num]) {
                                size_t remaining = static_cast<size_t>(i1[num]) - offset;
                                size_t freePending = SOFTWAREBUFFERSIZE - txPendingLen[num];
                                size_t queued = min(remaining, freePending);
                                if (queued > 0) {
                                    memcpy(txPending[num] + txPendingLen[num],
                                           buf1[num] + offset, queued);
                                    txPendingLen[num] += queued;
                                }
                            }
                            i1[num] = 0;
                        }
                    }
                }
#endif

                if (COM[num]->available()) {
                    int readCount = COM[num]->read(&buf2[num][0], SOFTWAREBUFFERSIZE); // Read up to SOFTWAREBUFFERSIZE bytes from the serial device.
                    if (readCount == 0)
                        continue;
#ifdef PROTOCOL_TCP
                    for (byte cln = 0; cln < MAX_NMEA_CLIENTS; cln++) {
                        if (TCPClient[num][cln])
                            TCPClient[num][cln].write(buf2[num], readCount);
                    }
#endif

#ifdef ESP32
#ifdef PROTOCOL_UDP
                    udp[num]->broadcastTo(buf2[num], readCount, udp_port[num]);
#endif
#ifdef BLUETOOTH
                    // now send to Bluetooth:
                    if (num == BLUETOOTH && SerialBT.hasClient())
                        SerialBT.write(buf2[num], readCount);
#endif
#endif
                }
            }
        }
    }

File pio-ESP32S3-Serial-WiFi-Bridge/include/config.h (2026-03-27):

/*********************************************************************************
 * config.h
 * 
 * Added compatibility for ESP8266  -- Yuri - Aug 2021
 * Incremented  version to 2.0      -- Yuri - Apr 2023
 * Implemented UDP + bug fixes      -- Yuri - Apr 2023
 * 
*********************************************************************************/
#ifndef CONFIG_H
#define CONFIG_H

#define DEBUG  // comment to suppress system serial messages

#ifdef ESP32
#include <WiFi.h>
#endif

//#define OTA_HANDLER          // uncomment to enable OTA programming

#define SSID     "ssid_esp_uart_bridge3x3"      // SSID to join (or broadcast)
#define PASSWD   "password_esp_uart_bridgeAAAA"  // wiFi password
#define HOSTNAME "ESP32-S3"     // hostname for STA mode mDNS

#define SOFTWAREBUFFERSIZE 1024
#define HARDWAREBUFFERSIZE 4096

#ifdef ESP32
#define VERSION "2.0-ESP32-S3"
#endif

#define MODE_AP                // MODE_STA or MODE_AP
#define PROTOCOL_TCP           // uncomment to enable TCP server
#define MAX_NMEA_CLIENTS 1     // max TCP clients
//#define PROTOCOL_UDP         // uncomment to enable UDP broadcast
//#define BLUETOOTH 0          // uncomment to create a bluetooth serial bridge on the indicated serial port
//#define BATTERY_SAVER        // uncomment to reduce wifi power

#define STATIC_IP IPAddress(192, 168,   4, 1)  // static IP for MODE_AP
#define NETMASK   IPAddress(255, 255, 255, 0)  // netmask for MODE_AP

#ifdef ESP32
#define NUM_COM   3    // 3 available on ESP32-S3
//#define NUM_COM   1    // 3 available on ESP32-S3
#endif

/**************************  COM Port 0 *******************************/
#define UART_BAUD0 115200           // Baudrate UART0
#define SERIAL_PARAM0 SERIAL_8N1    // Data/Parity/Stop UART0 (use SWSERIAL_* for ESP8266)
#define SERIAL0_TXPIN 43            // transmit Pin UART0
#define SERIAL0_RXPIN 1             // receive Pin UART0
#define SERIAL0_CTSPIN 16           // CTS Pin UART0
#define SERIAL0_RTSPIN 15           // RTS Pin UART0
#define SERIAL0_TCP_PORT 8880       // TCP Port UART0
#define SERIAL0_UDP_PORT 14550      // UDP Port UART0
/*************************  COM Port 1 *******************************/
#define UART_BAUD1 115200           // Baudrate UART1
#define SERIAL_PARAM1 SERIAL_8N1    // Data/Parity/Stop UART1 (use SWSERIAL_* for ESP8266)
#define SERIAL1_TXPIN 17            // transmit Pin UART1
#define SERIAL1_RXPIN 18            // receive Pin UART1
#define SERIAL1_CTSPIN 10           // CTS Pin UART1
#define SERIAL1_RTSPIN 9           // RTS Pin UART1
#define SERIAL1_TCP_PORT 8881       // TCP Port UART1
#define SERIAL1_UDP_PORT 14551      // UDP Port UART1
/*************************  COM Port 2 *******************************/
#define UART_BAUD2 115200           // Baudrate UART2
#define SERIAL_PARAM2 SERIAL_8N1    // Data/Parity/Stop UART2
#define SERIAL2_TXPIN 37            // transmit Pin UART2
#define SERIAL2_RXPIN 38            // receive Pin UART2
#define SERIAL2_CTSPIN 36           // CTS Pin UART2
#define SERIAL2_RTSPIN 35           // RTS Pin UART2
#define SERIAL2_TCP_PORT 8882       // TCP Port UART2
#define SERIAL2_UDP_PORT 14552      // UDP Port UART2

/**************************  DO NOT EDIT BELOW HERE **************************/
// perhaps a clever way to include/exclude serial debug messages...
#ifdef DEBUG
    #define debug Serial
#else
    class Debug: public Print {
        virtual size_t write(byte b) { return 0; }
    };
    Debug debug;
#endif

#endif  // CONFIG_H

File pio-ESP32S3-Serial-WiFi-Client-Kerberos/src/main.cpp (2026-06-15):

/*
  pio-ESP32S3-Serial-WiFi-Client-Kerberos (3x UART concurrent bridge)
  - Makes 3 TCP client connections (one per UART) to ESP-Serial-Bridge server
  - Bridges UART0/UART1/UART2 <-> TCP sockets concurrently (non-blocking)

  Adjusted by takurx and Generated by ChatGPT 5.2

  Notes:
  - UART0 is usually used for USB programming/logging; using it for external RX/TX may affect uploads.
    The pin assignment below matches the repo README wiring suggestion:
      COM0 Rx <-> GPIO01, COM0 Tx <-> GPIO43, COM0 CTS <-> GPIO16, COM0 RTS <-> GPIO15
      COM1 Rx <-> GPIO18, COM1 Tx <-> GPIO17, COM1 CTS <-> GPIO10, COM1 RTS <-> GPIO09
      COM2 Rx <-> GPIO38, COM2 Tx <-> GPIO37, COM2 CTS <-> GPIO36, COM2 RTS <-> GPIO35
    (from repository README)  :contentReference[oaicite:1]{index=1}

  - If you want to keep USB Serial for logs, consider:
      * Use UART1 + UART2 + (SoftwareSerial) as 3rd, or
      * Move COM0 away from UART0 pins and use HardwareSerial(1/2) + an extra via IO matrix (advanced).
*/

#include <Arduino.h>
#include <WiFi.h>
#include <WiFiClient.h>
#include "client_config.h"

// -------- UART definitions --------
struct UartBridge {
  HardwareSerial* ser;
  int uart_num;
  int rx_pin;
  int tx_pin;
  int cts_pin;
  int rts_pin;
  uint32_t baud;
  bool invert;
};

// Default pinning from repo README (COM0/1/2)
static UartBridge UARTS[3] = {
  { &Serial,  0, UART0_RX_PIN, UART0_TX_PIN, UART0_CTS_PIN, UART0_RTS_PIN, UART0_BAUD, UART0_INVERT },
  { &Serial1, 1, UART1_RX_PIN, UART1_TX_PIN, UART1_CTS_PIN, UART1_RTS_PIN, UART1_BAUD, UART1_INVERT },
  { &Serial2, 2, UART2_RX_PIN, UART2_TX_PIN, UART2_CTS_PIN, UART2_RTS_PIN, UART2_BAUD, UART2_INVERT },
};

// -------- TCP clients --------
static WiFiClient clients[3];
static uint32_t lastReconnectMs[3] = {0, 0, 0};

// -------- TX pending queue (TCP->UART) --------
static uint8_t txPendingBuf[3][TX_PENDING_SIZE];
static size_t txPendingLen[3] = {0, 0, 0};

static inline bool connectClient(int i) {
  if (clients[i].connected()) return true;

  const uint32_t now = millis();
  if (now - lastReconnectMs[i] < RECONNECT_INTERVAL_MS) return false;
  lastReconnectMs[i] = now;

  clients[i].stop();
  bool ok = clients[i].connect(BRIDGE_HOST, BRIDGE_PORTS[i]);
  if (ok) {
    if (TCP_NODELAY) clients[i].setNoDelay(true);
    //if (CLIENT_KEEPALIVE_SEC > 0) clients[i].keepAlive(CLIENT_KEEPALIVE_SEC, CLIENT_KEEPALIVE_SEC, CLIENT_KEEPALIVE_SEC);
  }
  return ok;
}

static inline void pumpSerialToTcp(int i) {
  auto* s = UARTS[i].ser;
  auto& c = clients[i];
  if (!c.connected()) return;

  int avail = s->available();
  if (avail <= 0) return;

  uint8_t buf[TX_CHUNK];
  int n = s->readBytes(buf, (avail > (int)sizeof(buf)) ? sizeof(buf) : avail);
  if (n > 0) {
    c.write(buf, n);
  }
}

static inline void pumpTcpToSerial(int i) {
  auto* s = UARTS[i].ser;
  auto& c = clients[i];
  if (!c.connected()) return;

  // Flush any previously queued bytes first
  if (txPendingLen[i] > 0) {
    size_t writable = s->availableForWrite();
    if (writable > 0) {
      size_t toSend = min(writable, txPendingLen[i]);
      size_t sent = s->write(txPendingBuf[i], toSend);
      if (sent > 0) {
        txPendingLen[i] -= sent;
        if (txPendingLen[i] > 0) {
          memmove(txPendingBuf[i], txPendingBuf[i] + sent, txPendingLen[i]);
        }
      }
    }
  }

  int avail = c.available();
  if (avail <= 0) return;

  uint8_t buf[RX_CHUNK];
  int n = c.read(buf, (avail > (int)sizeof(buf)) ? sizeof(buf) : avail);
  if (n <= 0) return;

  // Write what fits immediately into the UART TX buffer
  size_t offset = 0;
  size_t writable = s->availableForWrite();
  if (writable > 0) {
    size_t immediate = min((size_t)n, writable);
    size_t sent = s->write(buf, immediate);
    offset = sent;
  }

  // Queue the remainder into txPendingBuf
  if (offset < (size_t)n) {
    size_t remaining = (size_t)n - offset;
    size_t freePending = TX_PENDING_SIZE - txPendingLen[i];
    size_t queued = min(remaining, freePending);
    if (queued > 0) {
      memcpy(txPendingBuf[i] + txPendingLen[i], buf + offset, queued);
      txPendingLen[i] += queued;
    }
  }
}

void setupUart(int i) {
  // Arduino-ESP32 allows inversion via begin() 6th arg in newer cores; to be safe, set later if needed.
  // UARTS[1], CTS 20 -> USB D-, RTS 19 -> USB D+ だと競合する気がするので、他のピンに割り当てたい -> UARTS[1], CTS 10, RTS 09 にした

  // Expand HW UART RX/TX buffers (must be called before begin())
  UARTS[i].ser->setRxBufferSize(HARDWARE_BUFFER_SIZE);
  UARTS[i].ser->setTxBufferSize(HARDWARE_BUFFER_SIZE);
  // Flow control disable
  UARTS[i].ser->begin(UARTS[i].baud, SERIAL_8N1, UARTS[i].rx_pin, UARTS[i].tx_pin, UARTS[i].invert);
  UARTS[i].ser->setHwFlowCtrlMode(UART_HW_FLOWCTRL_DISABLE); // TODO: flow control handling in software if needed
  pinMode(UARTS[i].cts_pin, OUTPUT); // CTS as input (not used if flow control disabled, but set to known state)
  pinMode(UARTS[i].rts_pin, OUTPUT); // RTS as output (not used if flow control disabled, but set to known state)
  digitalWrite(UARTS[i].cts_pin, LOW);
  digitalWrite(UARTS[i].rts_pin, LOW);
  UARTS[i].ser->setTimeout(0);

  /* // Flow control enable
  UARTS[i].ser->begin(UARTS[i].baud, SERIAL_8N1, UARTS[i].rx_pin, UARTS[i].tx_pin, UARTS[i].invert);
  UARTS[i].ser->setPins(UARTS[i].rx_pin, UARTS[i].tx_pin, UARTS[i].cts_pin, UARTS[i].rts_pin);
  UARTS[i].ser->setHwFlowCtrlMode(UART_HW_FLOWCTRL_CTS_RTS);
  UARTS[i].ser->setTimeout(0);
  */
}

void setupWifi() {
  WiFi.mode(WIFI_STA);
  WiFi.begin(WIFI_SSID, WIFI_PASS);

  const uint32_t t0 = millis();
  while (WiFi.status() != WL_CONNECTED) {
    delay(200);
    if (millis() - t0 > WIFI_CONNECT_TIMEOUT_MS) break;
  }
}

void setup() {
  // If you keep UART0 for external device, avoid using Serial for logging here.
  // If you keep USB logging, you must not steal UART0 pins.

#if ENABLE_USB_LOG
  Serial.begin(115200);
  delay(200);
#endif

  setupWifi();

  for (int i = 0; i < 3; i++) {
    setupUart(i);
  }

  // Initial connect attempts
  for (int i = 0; i < 3; i++) {
    connectClient(i);
  }
}

void loop() {
  // Ensure WiFi
  if (WiFi.status() != WL_CONNECTED) {
    // Try reconnect WiFi periodically
    static uint32_t lastWiFiTry = 0;
    uint32_t now = millis();
    if (now - lastWiFiTry > 2000) {
      lastWiFiTry = now;
      WiFi.disconnect(false);
      WiFi.begin(WIFI_SSID, WIFI_PASS);
    }
    //delay(10);
    return;
  }

  // Ensure TCP connections (3 sockets)
  for (int i = 0; i < 3; i++) {
    connectClient(i);
  }

  // Pump both directions for each UART
  for (int i = 0; i < 3; i++) {
    pumpSerialToTcp(i);
    pumpTcpToSerial(i);

    // If server closed the connection, stop() so reconnect logic can run cleanly
    if (clients[i].connected() && !clients[i].available() && !clients[i]) {
      clients[i].stop();
    }
  }

  // small yield to WiFi stack
  delay(1);
}

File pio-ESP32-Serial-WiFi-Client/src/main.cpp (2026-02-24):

/*********************************************************************************
 * ESP32-Serial-WiFi-Client
 *
 * Simple ESP32 TCP or UDP client for use with ESP-Serial-Bridge
 *
 *   -- Yuri - Apr 2023
 *
 * Disclaimer: Don't use for life support systems or any other situation
 * where system failure may affect user or environmental safety.
 *********************************************************************************/

#include <Arduino.h>
#include <ESPmDNS.h>
#include <WiFi.h>
#include <esp_wifi.h>
#include "esp_system.h"

#include "client_config.h"

#ifdef PROTOCOL_TCP
#include <WiFiClient.h>
#elif defined(PROTOCOL_UDP)
#include <AsyncUDP.h>
#endif

#ifdef OTA_HANDLER
#include <ArduinoOTA.h>
#endif

uint8_t buf[BUFFERSIZE];
uint16_t num = 0;

const int wdtTimeout = 30000;  // reboot after 30 seconds of no host
hw_timer_t *timer = NULL;

void ARDUINO_ISR_ATTR resetModule() {
  debug.println("Rebooting...");
  esp_restart();
}

#ifdef PROTOCOL_TCP
WiFiClient client;
void connect_to_host() {
  debug.printf("Connecting to %s:%d...", HOST_IP.toString(), HOST_PORT);
  debug.println("while, connect_to_host");
  while (!client.connect(HOST_IP, HOST_PORT)) {
    delay(500);
    debug.print('.');
  }
  debug.println("connected, connect_to_host\n");
  delay(1000);
}
#endif

#ifdef PROTOCOL_UDP
AsyncUDP udp;
#endif

void WiFiStationDisconnected(WiFiEvent_t event, WiFiEventInfo_t info) {
  debug.print("WiFi disconnected: ");
  debug.println(info.wifi_sta_disconnected.reason);
  debug.println("Trying to reconnect..");
  WiFi.begin(SSID, PASSWD);
  debug.println("while, WiFiStationDisconnected");
  while (WiFi.status() != WL_CONNECTED) {
    delay(500);
    debug.print(".");
    if(client.connect(HOST_IP, HOST_PORT)) {
        break;
    }
  }
  debug.println("connected, WiFiStationDisconnected");
  debug.print("IP address: ");
  debug.println(WiFi.localIP());
}

void setup() {
  delay(500);

  Serial.begin(CLIENT_BAUD, CLIENT_PARAM, CLIENT_RXPIN, CLIENT_TXPIN);

  debug.print("\n\nWiFi serial bridge client ");
  debug.println(VERSION);

  debug.println("Open ESP Station Mode");
  WiFi.mode(WIFI_STA);
  WiFi.onEvent(WiFiStationDisconnected, ARDUINO_EVENT_WIFI_STA_DISCONNECTED);
  WiFi.begin(SSID, PASSWD);
  debug.print("Connecting to: ");
  debug.print(SSID);
  debug.print("..");

  // ESP32 (Arduino Core) 2.0系から3.0系への移行 | なんでも独り言
  // https://ehbtj.com/electronics/migrating-from-esp32-arduino-core-v2-to-v3/
  // 3.0系
  // timer = timerBegin(1000000);                     //timer 1MHz
  // timerAttachInterrupt(timer, &resetModule);       //attach callback
  // timerAlarm(timer, wdtTimeout * 1000, false, 0);  //set time in us
  // 2.0系
  // timer = timerBegin(0, 1000000, true);                    //timer 1MHz
  timer = timerBegin(0, 16960, true);                    //timer 1MHz
  timerAttachInterrupt(timer, &resetModule, true);      //attach callback
  timerAlarmWrite(timer, wdtTimeout * 1000, true);     //set time in us
  timerAlarmEnable(timer);                        //enable interrupt
  debug.println("Watch dog timer Setup done");

  debug.println("while, setup");
  while (WiFi.status() != WL_CONNECTED) {
    delay(500);
    debug.print(".");
  }
  timerWrite(timer, 0);  //reset timer (feed watchdog)
  debug.println("connected, setup");
  debug.print("IP address: ");
  debug.println(WiFi.localIP());

#ifdef OTA_HANDLER
  ArduinoOTA.onStart([]() {
    String type;
    if (ArduinoOTA.getCommand() == U_FLASH)
      type = "sketch";
    else  // U_SPIFFS
      type = "filesystem";

    // NOTE: if updating SPIFFS this would be the place to unmount SPIFFS
    // using SPIFFS.end()
    Serial.println("Start updating " + type);
  });
  ArduinoOTA.onEnd([]() {
    Serial.println("\nEnd");
  });
  ArduinoOTA.onProgress([](unsigned int progress, unsigned int total) {
    Serial.printf("Progress: %u%%\r", (progress / (total / 100)));
  });
  ArduinoOTA.onError([](ota_error_t error) {
    Serial.printf("Error[%u]: ", error);
    if (error == OTA_AUTH_ERROR)
      Serial.println("Auth Failed");
    else if (error == OTA_BEGIN_ERROR)
      Serial.println("Begin Failed");
    else if (error == OTA_CONNECT_ERROR)
      Serial.println("Connect Failed");
    else if (error == OTA_RECEIVE_ERROR)
      Serial.println("Receive Failed");
    else if (error == OTA_END_ERROR)
      Serial.println("End Failed");
  });

  ArduinoOTA.begin();
#endif

#ifdef PROTOCOL_UDP
  if (udp.listen(HOST_PORT)) {
    debug.printf("Listening on UDP port %d\n", HOST_PORT);
    udp.onPacket([](AsyncUDPPacket packet) {
      if (packet.localPort() == HOST_PORT)
        Serial.write(packet.data(), packet.length());
    });
  }
#endif
}

void loop() {
#ifdef OTA_HANDLER
  ArduinoOTA.handle();
#endif

  timerWrite(timer, 0);  //reset timer (feed watchdog)

#ifdef PROTOCOL_TCP
  if (!client.connected()) {
    connect_to_host();
  }

  while (client.available()) {
    buf[num] = client.read();
    num++;
    if (num == BUFFERSIZE - 1) break;
  }
  if (num > 0) Serial.write(buf, num);
  num = 0;
#endif

  while (Serial.available()) {
    buf[num] = Serial.read();
    num++;
    if (num == BUFFERSIZE - 1) break;
  }
#ifdef PROTOCOL_TCP
  if (num > 0) client.write(buf, num);
#elif defined(PROTOCOL_UDP)
  //udp.broadcastTo(buf, num, HOST_PORT + 1);
  udp.broadcastTo(buf, num, HOST_PORT);
#endif
  num = 0;
}

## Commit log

2025-10-07 tested UDP and TCP -> It is better TCP on my environment
    tested UDP and TCP -> It is better TCP on my environment
    - case of UDP
    Ok, Host -> Client communication
    Broken, Client -> Host communication
    - case of TCP
    Ok, bi-direction, Host -> Client and Client <- Host
    [ESP32-Serial-WiFi-Client.ino, client_config.h, config.h]
2025-10-07 config.hを変えてみたりしたが変わらない
    config.hを変えてみたりしたが変わらない
    - Host -> Client, around 13000 bps, 1/10
    - Client -> Host, around 115200 bps
2025-10-08 test adding watch dog timer, wdt
    test adding watch dog timer, wdt
2025-12-17 Host側が落ちた時に無限ループかつWatch dog timerが効かなかったエラーを修正
    Host側が落ちた時に無限ループかつWatch dog timerが効かなかったエラーを修正
    1. Client側が落ちた場合（ClientのReset）→Host側からの入力で回復
    2. Host側が落ちてすぐ回復した場合（HostのReset）→OK
    3. Host側が落ちて回復しない場合（HostのOFF）→30sごとにWatch dog TimerでClientをReset
    の3ケースに対応した
    [ESP32-Serial-WiFi-Client.ino]
2025-12-19 add case, 3d printer
    add case, 3d printer
    [251215_ESP32_uart_bridge_box.stl, 251215_ESP32_uart_bridge_box_cover.stl, 251216_ESP32_uart_bridge_box_cover_v2.stl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]
2026-01-27 update README with cline+claude sonnet 4.5
    update README with cline+claude sonnet 4.5
    >変更点を英語と日本語でREADME.mdの Takurx's Notesの章に箇条書きでまとめてみて
2026-01-27 add PCB ESP-Serial-Bridge V1.0
    add PCB ESP-Serial-Bridge V1.0
    [esp_serial_bridge_pcb-B_Cu.gbr, esp_serial_bridge_pcb-B_Mask.gbr, esp_serial_bridge_pcb-B_Paste.gbr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]
2026-01-27 add PCB ESP32S3-Serial-Bridge V1.0 (Working In Progress)
    add PCB ESP32S3-Serial-Bridge V1.0 (Working In Progress)
    [esp32s3_serial_bridge_pcb.kicad_pcb, esp32s3_serial_bridge_pcb.kicad_sch]
2026-01-28 add PCB ESP32S3-Serial-Bridge V1.0 Kerberos
    add PCB ESP32S3-Serial-Bridge V1.0 Kerberos
    [ESP32-S3-DevKit-3rd-party-hole-position-calculate.xlsx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]
2026-02-10 add ESP32-Serial-WiFi-Client-Kerberos Bridge
    It is ESP32 x3 UART - ESP32 x3 UART, Wi-Fi Bridge and physical in/out put
2026-02-13 test kerberos to platfromio (not yet, work on board)
    test kerberos to platfromio (not yet, work on board)
2026-02-13 test Bridge (Host), not yet work on board
    test Bridge (Host), not yet work on board
2026-02-13 test client, not yet work on board
    test client, not yet work on board
2026-02-17 checked speed, working is ok, speed is enough?
    各3ポート115200bpsで乱数を送る設定で、
    Host x3→Client x3、各ポート600～45000 bps
    Host x3←Client x3、各ポート7000～13000 bps
2026-02-17 ESP32S3用に調整中......
    ESP32S3用に調整中......
2026-02-24 ok, working. fix serial begin function
    ok, working. fix serial begin function
    [main.cpp]
2026-02-24 ひとまずHostのcom0だけflow controlを追加してみるテスト
    ひとまずHostのcom0だけflow controlを追加してみるテスト
2026-02-24 Hostのcom0, com2はOK
    Hostのcom0, com2はOK
    com1を変更するとdebugメッセージでなくなるのでピン配置を確認する
2026-02-24 CTS 20 -> USB D-, RTS 19 -> USB D+ で競合する気がするので、他のピンに割り当てたい
    CTS 20 -> USB D-, RTS 19 -> USB D+ で競合する気がするので、他のピンに割り当てたい
2026-02-24 client-kerberosの方もcom0, com2はOK, com1を回避した
    client-kerberosの方もcom0, com2はOK, com1を回避した
    com1のピン配置を変えてリトライする
2026-02-24 まずはflow controlあり
    まずはflow controlあり
2026-02-24 flow controlありの方が気持ち速そう
    flow controlあり
    host -> client, Average 82000 bps
    host <- client, Average 20000 bps
    flow controlなし
    host -> client, average 50000 bps
    host <- client, Average 20000 bps
2026-02-25 動作OK, CTS: GPIO20 -> 10, RTS: GPIO19 -> 9に変更
    動作OK, CTS: GPIO20 -> 10, RTS: GPIO19 -> 9に変更
    COM[1], CTS 20 -> USB D-, RTS 19 -> USB D+ だと競合して動作してない気がしたので
2026-02-25 client側はok
    client側はok
2026-02-25 ひとまずcom1なし
    ひとまずcom1なし
2026-02-25 hostもok
    hostもok
2026-02-25 動作ok
    動作ok
2026-02-25 PCBもCTS: GPIO20 -> 10, RTS: GPIO19 -> 9 に変更
    PCBもCTS: GPIO20 -> 10, RTS: GPIO19 -> 9 に変更
    [esp32s3_serial_bridge_pcb.kicad_pcb, esp32s3_serial_bridge_pcb.kicad_sch]
2026-02-26 flow 制御あり、3方向同時の通信速度テスト
    flow 制御あり、3方向同時の通信速度テスト
2026-02-26 flow controlありでpythonがctrl+cできたりできなかったりする
    host <- clientでhost側のserial.print出力があやしい気がする
    3ポートそろわないと出力出なかったり？してるかもで
2026-03-13 add case
    add case
    [260313_v1_box_ESP32S3_Serial_WiFi_Bridge_Kerberos.stl, 260313_v1_cover_box_ESP32S3_Serial_WiFi_Bridge_Kerberos.stl]
2026-03-18 flow controlありだと、3ポートつながってRTS/CTSの操作がないと立ち上がらない
    flow controlありだと、3ポートつながってRTS/CTSの操作がないと立ち上がらない
    とくにpio-ESP32S3-Serial-WiFi-Bridgeの方、ポートオープンしないのは厳しい
    なので、基本はflow control disableにしておく
2026-03-19 flow controlなしにしたので、RTS/CTSのpin設定をcomment outした
    flow controlなしにしたので、RTS/CTSのpin設定をcomment outした
2026-03-19 buffer size 1024ぐらいが適切かも
    buffer size 1024ぐらいが適切かも
2026-03-27 念のためNo flow controlでもRTS, CTSを予定したピンをOUTPUT, LOWに
    念のためNo flow controlでもRTS, CTSを予定したピンをOUTPUT, LOWに
2026-03-27 回路をupdate
    回路をupdate
    [esp_serial_bridge_pcb.kicad_sch]
2026-03-27 serial flush interval from github copilot、問題解決にはちと違う気がする
    serial flush interval from github copilot、問題解決にはちと違う気がする
2026-03-27 ② TCP 読み込みを 1 バイトずつではなく一括に変更
    ② TCP 読み込みを 1 バイトずつではなく一括に変更
2026-03-27 新規TCPコネクション時にHardware Serial buffer をflushする、buffer sizeを明示化
    新規TCPコネクション時にHardware Serial buffer をflushする、buffer sizeを明示化
2026-06-23 Update speed test results with flow control details
    Update speed test results with flow control details
